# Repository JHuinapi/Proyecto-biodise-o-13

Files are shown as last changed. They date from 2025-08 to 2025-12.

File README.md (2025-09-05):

<table>
   <tr>
      <td valign="top">
         &nbsp;&nbsp;&nbsp;&nbsp;&nbsp;&nbsp;&nbsp;&nbsp;
      </td>
      <td valign ="middle">
         &nbsp;&nbsp;&nbsp;&nbsp;&nbsp;&nbsp;&nbsp;&nbsp;&nbsp;&nbsp;&nbsp;&nbsp;&nbsp;
      </td>
   </tr>
</table>

<h1>Fundamentos de Biodiseño</h1>
Bienvenidos al repositorio del grupo 13 del curso "Fundamentos de biodiseño" horario B403

Tema de interes: Trastornos neurológicos (esclerosis)

Integrantes:
- Mariam Michelle Morocho Bustamante - mariam.morocho@upch.pe
- Alexandra Milagros Mamani Casas - alexandra.mamani@upch.pe
- Luis Antonio Gutierrez Nuñez - luis.gutierrez.n@upch.pe
- Jonatan Esteban Huiñapi Huaman - jonatan.huinapi@upch.pe
- Ricardo Sebastian Murillo Sedano -  ricardo.murillo@upch.pe
- Xavier Alexis Hernandez Jeronimo - xavier.hernandez@upch.pe

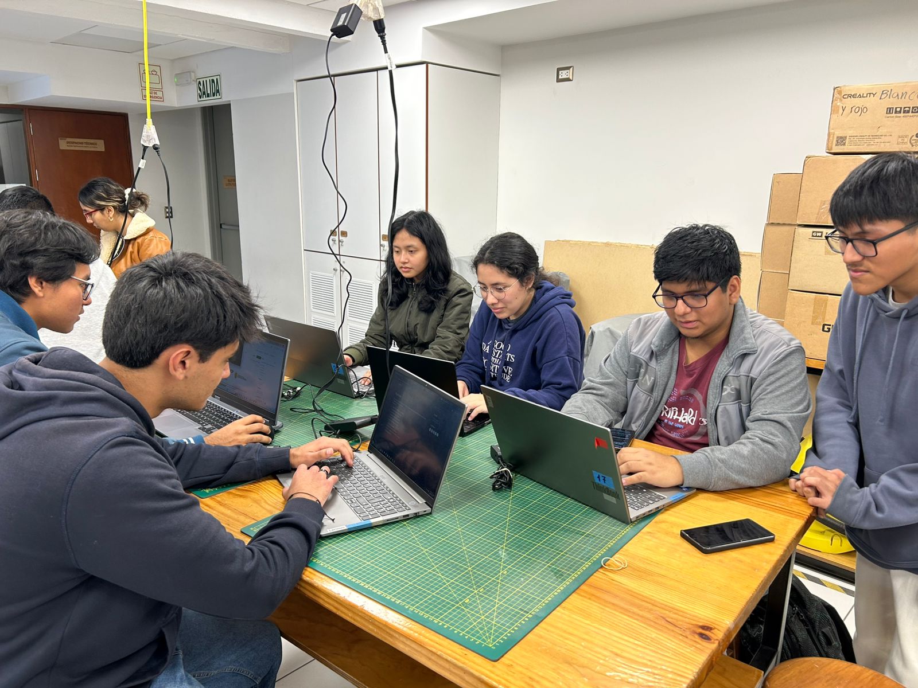
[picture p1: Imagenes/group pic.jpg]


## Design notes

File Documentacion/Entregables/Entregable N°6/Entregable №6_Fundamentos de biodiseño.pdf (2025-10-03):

Entregable №6: Metodología VDI - Parte 1

### 1. Checkpoint 1 – Business Case (¿Por qué hacemos este proyecto?)

a. Situación inicial
¿Cuál es el problema, necesidad o contexto que motiva el desarrollo?

El problema surge a partir de una lesión medular completa de tipo A en el nivel T10 ocasionada en su trabajo como mecánico. A pesar de lo mencionado, presenta una zona de preservación parcial ZPP por lo que retiene algo de sensibilidad y de movimiento de forma parcial y puede flexionar la cadera.
Actualmente, por su lesión el paciente necesita el apoyo de dos bastones canadienses y de dos soportes largos (ortesis) al momento de desplazarse. Estos últimos le brindan estabilidad y pueden trabarse y destrabarse a nivel de la rodilla dependiendo de la acción que necesite hacer el usuario.
El desplazamiento se ve limitado ya que las ortesis se accionan de forma manual requiriendo el apoyo de terceros. Por lo mismo existe la necesidad de optimizar la marcha sobre todo en la zona de la rodilla de forma que es posible reducir su dependencia al momento de trasladarse.
b. Objetivos estratégicos
¿Qué metas técnicas, económicas y organizativas debe cumplir el proyecto?

Este proyecto tiene diversos objetivos, establecidos en base a los problemas cotidianos y dificultades que presentó nuestro paciente. Por el apartado técnico, principalmente se vio necesario incluir de algún modo le ayude a sostenerse y distribuir su peso de una forma que sea más favorable para que las zonas funcionales soporten el peso de su propio cuerpo, por ejemplo, con muletas, un andador, un exoesqueleto, etc. En el caso del paciente planeamos incluir una forma de que pueda controlar del trabe y destrabe de su rodilla con movilidad de manera remota, para evitar las dificultades que incluyen el hacerlo manualmente. Además, el paciente necesitaba saber cómo están posicionadas sus piernas, ya que no posee sensibilidad en estas, y sería primordial para evitar posibles daños en estas. La forma de lograr esto fue prevista a través de sensores que puedan analizar el ángulo de incidencia y la presión o fuerza realizada sobre el piso.

Por el lado económico, se propuso como meta de que el dispositivo no sea muy caro, de esta manera se pensó en un modelo que sea simple y que priorice cumplir con su objetivo, por encima del resto de cosas. En ese sentido se busca un material que sea resistente con el tiempo, que los componentes requieran de poco mantenimiento y que el dispositivo recubra solo zonas esenciales para que no sea muy robusto el modelo, así reduciendo el costo de producción y en consecuencia el de venta. Esto debido a que la mayoría de dispositivos que tratan de suplir con el problema son exoesqueletos u órtesis que resaltan a simple vista por su tamaño, además de ser en su mayoría muy costosas.

Nuestra meta organizativa es brindar una mejor calidad de vida a aquellas personas que hayan perdido la movilidad y que principalmente necesitan de soportes o ayuda para poder ejercer la marcha, brindándoles una alternativa de menor costo y con considerable vida útil.

c. Valor añadido
¿Qué beneficio aporta el sistema (para el usuario, para la empresa, para la sociedad)?

El valor añadido de nuestro sistema se refleja en tres niveles. Para el usuario, el principal beneficio es el incremento de la independencia funcional, ya que el mecanismo de trabe y destrabe optimizado elimina la necesidad de asistencia externa para esa función en particular, permitiendo transiciones más fluidas entre caminar y subir escalones, además se logra de está forma adecuarse a terrenos con más irregularidades. Esto se traduce en una experiencia de marcha más natural, disminuyendo la fatiga y aumentando la confianza en el desplazamiento. Asimismo, la incorporación de materiales adaptados minimiza el riesgo de lesiones por presión y mejora la comodidad durante su uso prolongado, garantizando el uso del dispositivo en la vida diaria. En el caso de la empresa, el prototipo constituye una innovación frente a ortesis tradicionales, al integrar un sistema mecánico de bloqueo automático mediante engranajes y topes que ofrece mayor eficiencia y seguridad estructural en la rodilla. Esta solución, además de ser más práctica para el usuario, se caracteriza por su simplicidad mecánica, lo que facilita tanto su fabricación como su mantenimiento, aumentando el atractivo del producto frente a sistemas más complejos o costosos. De esta forma, no solo presenta un avance técnico, sino también una oportunidad para diferenciarse en el mercado de dispositivos ortopédicos. Finalmente, para la sociedad, el dispositivo aporta un impacto positivo al favorecer la inclusión y movilidad de personas con lesión medular, lo que contribuye a mejorar su participación en actividades cotidianas y a reducir su dependencia de cuidadores o familiares. A nivel sanitario, puede disminuir complicaciones médicas derivadas de la inmovilidad prolongada, como úlceras por presión o problemas musculoesqueléticos, generando así un beneficio en la calidad de vida del paciente y una reducción potencial en los costos asociados a la atención médica. En un sentido más amplio, el proyecto promueve el avance de soluciones biomédicas accesibles e impulsa el desarrollo de tecnologías sociales que buscan mejorar la autonomía y bienestar de esta población.

d. Stakeholders
¿Quiénes son los usuarios, clientes y partes interesadas clave?

Este proyecto está dirigido a personas que han perdido parcialmente la movilidad de sus piernas. Personas que aún pueden caminar, pero que necesitan bastones u otros soportes largos para poder desplazarse, ya que no cuentan con la capacidad de flexionar desde la cadera hacia abajo y, en relación con el tren inferior, únicamente disponen de los flexores de cadera. En otras palabras, el destrabe y trabe de la rodilla depende de una ortesis, dado que la persona no cuenta con la posibilidad de flexionar la pierna por su propia cuenta.

Es por ello que el propósito del proyecto es ofrecerles una manera de caminar más fluida y cómoda. Las ortesis mecánicas tradicionales ayudan a bloquear y desbloquear los ejes que permiten el movimiento al andar, pero muchas veces no son prácticas, pues pueden bloquearse de forma involuntaria y dificultar el paso. Por eso, este proyecto busca brindar una alternativa pensada especialmente para quienes tienen movilidad reducida y han perdido la sensibilidad en la parte inferior del cuerpo.

Asimismo, dentro de las partes interesadas destacamos a la propia familia del usuario, ya que presentar una discapacidad es un golpe duro tanto para la persona que la experimenta como para sus familiares, quienes asumen un peso emocional y una dificultad económica añadida. Del mismo modo, asociaciones, fundaciones y organizaciones que apoyan a personas con discapacidad de bajos recursos también forman parte de los interesados, puesto que, a través de ellas, el trabajo desarrollado puede tener un mayor alcance y permitir que estas personas retomen y realicen de manera más cómoda y rápida actividades tan cotidianas como caminar o subir escaleras.

e. Competencias y equipo
¿Se cuenta con el conocimiento, habilidades y recursos adecuados?

Para poder realizar el proyecto se requiere tener un conocimiento sobre la situación en la que se encuentra el paciente y cuál es la ayuda que requiere específicamente. A partir de estos aspectos se construye una idea de solución, la cual es la automatización del proceso del trabe y destrabe de rodilla facilitado por una órtesis. Para poder construir esta idea se requiere tener conocimiento sobre el funcionamiento del sistema que permite este proceso. Este conocimiento fue adquirido al realizar una exhaustiva revisión de diversas patentes que contaban con esta funcionalidad.
En cuanto a las habilidades necesarias para completar el proyecto, se requiere conocer cómo trabajar con sensores y el sistema Arduino para poder realizar el código que se requiere que sigan estos sensores. Además, para poder realizar el producto se requiere saber cómo manejar algún programa de modelado 3D para poder construir, y posteriormente imprimir, las secciones de la solución que lo requieran.
Los recursos adecuados para poder realizar el proyecto serían sensores para poder calcular el ángulo de flexión de la rodilla, placa bluetooth para facilitar el trabe y destrabe de rodilla, programa Arduino Uno para realizar el código, placa Arduino Uno para ejecutar el código, programa de modelado 3D para poder visualizar el producto y filamentos para impresión 3D en caso se requiera imprimir alguna parte del producto.
f. Planificación inicial
¿Cuál es el cronograma preliminar, presupuesto y posibles riesgos?

El cronograma preliminar iniciará a partir de la semana 7, hasta la semana 16.

Semana | Objetivo
7 | Checkpoint 1- Business Case: Definición de solución y necesidades técnicas, económicas y materiales del producto a realizar en base a la necesidad del paciente.
8 | Checkpoint 2 y 3: Organización de la solución, indicando las características, estructura de funciones, lista de requerimientos, materiales.
9 | Hito N°1
10 | Modelado 3D de elementos propios de la solución.
11 | Prototipado electrónico de solución (parte 1)
12 | Prototipado electrónico de la solución (parte 2)
13 | Integración del prototipado electrónico y piezas 3D (formación de primer prototipo completo)
14 | Validación del prototipo de baja fidelidad con pruebas de uso
15 | Hito N°2
16 | Presentación final del proyecto. Incluye el informe técnico, sustentación oral y presentación de pósters.

Para la realización del presupuesto, cabe recalcar que la realización de esta solución no indica un cambio en el esqueleto de los soportes metálicos y el bastón canadiense que se utilizan en la solución. Se muestran los precios del soporte metálico producido en el INR, con los precios para pacientes con afiliación al SIS, INR, Essalud y seguros privados respectivamente. El usuario, al no poseer sensibilidad en ningún MI, utiliza dos soportes metálicos largos simples y dos bastones canadienses.

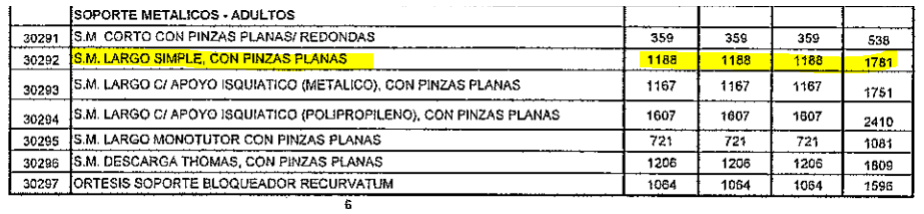
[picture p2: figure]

Fig 1. Precio de soporte metálico largo simple del tarifario INR-2015 [1]

Asimismo, se tomará en cuenta un principio mecánico para realizar el frenado de la rodilla. El cual actuará al obtener la información de los sensores de presión plantar, los cuales pueden ser cubiertos por 4 o 5 sensores de presión (1 Sensor FlexiForce A201-100 (0-445 N) en parte del talón y 3 sensores FSR-402 ( para los metatarsos) para abarcar gran parte del área del pie y cumplir con el rango de medición. Estos serán acompañados con un sensor que mida posición, velocidad y aceleración angular para obtener la fase de marcha del usuario, para este caso, se aplicarán dos sensores MPU 9250, uno ubicado en el muslo y otro ubicado en la tibia, con el fin de obtener las mediciones relativas. Además, es importante considerar un microcontrolador con capacidad de comunicación por Bluetooth como el ESP-32, los cuales irían como maestro (alrededor de la rodilla) y seguidores (en el bastón canadiense y cerca de la planta del pie). Asimismo, se necesitan actuadores como el solenoide pull type sobre un freno simple como el bloqueo de trinquete suizo. Sin embargo, este puede ser modelado en 3D para añadir aberturas para conexión con los actuadores.
Necesita 3 baterías recargables para cada parte del producto, con una grande para abarcar el solenoide y otras más chicas para los sensores plantares y del bastón.

Elemento | Cantidad | Costo unitario | Costo Total (s/.)
Bastón tipo canadiense de PP (adultos) [2] | 2 | 55 | 110
S.M. Largo simple con pinzas planas[1] | 2 | 1781 | 3562
Sensor FlexiForce A201-100 [3] | 1 | 22.95 USD | 80.28
Sensor FSR-402 [4] | 3 | 30 | 90
Sensor MPU 9250 [5] | 2 | 65 | 130
Microcontrolador ESP-32 [6] | 3 | 30 | 90
Solenoide electromagnético JF-0630B [7] | 1 | 21 | 21
Batería lipo 3S 11.4 V | 1 | 102.5 | 102.5
Batería lipo 1S 3.7V | 2 | 23 | 46
Total | | | 4221.28

Finalmente, este producto busca la modificación de uno de los bastones canadienses y uno de los soportes largos, por lo que para un prototipo, se puede prescindir de uno de cada uno, lo cual deja un mínimo de s/.2395,28. Por el lado de los componentes utilizados, se emplearán s/. 559,28 sin considerar costos por material de impresión 3D (PLA) y elementos de bajo costo como las resistencias, placas, cables y cuerdas que conectan a los motores con el bloqueador.

Finalmente, los riesgos se encontrarán en la falla del sistema de frenado, al no propiciar la suficiente fuerza para mantener el bloqueo libre cuando se requiera. La falta de aceptación del paciente debido a la alza en el precio del producto. Así como una baja deficiente resistencia del material de impresión para soportar el bloqueo de la articulación de la rodilla.

Referencia de costos:

1. https://app.inr.gob.pe:444/media/html/transparencia/transparencia%20inr/resoluciones/2015/RD%20122-2015-SA-DG-INR.pdf (https://app.inr.gob.pe:444/media/html/transparencia/transparencia%20inr/resoluciones/2015/RD%20122-2015-SA-DG-INR.pdf)

[1]
“Bateria Lipo 3.7V 600mAh 1S 25C Turnigy Nano-Tech”. Accedido: 2 de octubre
de | 2025. | | [En | línea]. | | Disponible | en:
https://sawers.com.pe/bateria-lipo-38v-520mah-80-160c
[2]
“ESP32 Devkit V1 30P”, Electromanía Perú. Accedido: 2 de octubre de 2025.
[En | | línea]. | | | Disponible | | en:
https://www.electromania.pe/producto/esp32-devkit-v1-30p/
[3]
“Solenoide Electromagnetico 12 VDC 3000mA 10mm Electroiman Solenoide”, Hi-Fi SAC Perú. Accedido: 2 de octubre de 2025. [En línea]. Disponible en: https://hifisac.com/shop/jf-0630b-solenoide-electromagnetico-12-vdc-3000ma-10 mm-electroiman-solenoide-3174 (https://hifisac.com/shop/jf-0630b-solenoide-electromagnetico-12-vdc-3000ma-10mm-electroiman-solenoide-3174)
[4]
“Sensor de Fuerza resistivo FSR402 / FSR406”, MTLAB. Accedido: 2 de octubre
de | 2025. | | [En | línea]. | | Disponible | en:
https://mtlab.pe/producto/sensor-de-fuerza-resistivo-fsr402-fsr406/
[5]
“ORTOPEDIA WONG e-commerce ”:, Ortopedia Wong. Accedido: 2 de octubre
de | 2025. | | [En | línea]. | | Disponible | en:
https://www.ventasortopediawong.pe/producto/baston-canadiense
[6]
“MPU9250: Acelerómetro + Giroscopio + Magnetómetro”, MTLAB. Accedido: 2
de | octubre | de | 2025. | [En | línea]. | Disponible | en:
https://mtlab.pe/producto/mpu9250-acelerometro-giroscopio-magnetometro/[7]
“FlexiForce Pressure Sensor - 100lbs.” Accedido: 2 de octubre de 2025. [En
línea]. | | | | Disponible | | | en:
https://www.sparkfun.com/flexiforce-pressure-sensor-100lbs.html
[8]
“Bateria Lipo DUPU Nanotech de 11.1Voltios 2200mAh 3S 24.4Wh Tamaño:105x35x25mm”, Hi-Fi SAC Perú. Accedido: 2 de octubre de 2025. [En
línea]. | | | | Disponible | | | en:

https://hifisac.com/shop/dupu-25c2200-bateria-lipo-dupu-nanotech-de-11-1voltio s-2200mah-3s-24-4wh-tamano-105x35x25mm-43 (https://hifisac.com/shop/dupu-25c2200-bateria-lipo-dupu-nanotech-de-11-1voltios-2200mah-3s-24-4wh-tamano-105x35x25mm-43)

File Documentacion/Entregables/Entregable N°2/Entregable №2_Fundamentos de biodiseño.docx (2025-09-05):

Entregable №2: Análisis del caso

1. —

1.1. Información Personal:

- Edad: 28
- Género: masculino
- Grado de instrucción: superior universitaria completa
- Trabajo: Actualmente desempleado
- Procedencia: natural de Lima
- Estado civil: soltero, sin hijos
- Regímenes de tratamiento médico o terapéutico y sus objetivos:

Se le pronóstica rehabilitación funcional y neurológica. Los objetivos del tratamiento o terapia médica serían:

- Locomoción independiente en silla de ruedas mecánica simple.
- Manejo funcional paciente y familia, transferencias y actividades de vida diaria .
- Manejo y prevención de complicaciones .
- Orientaciones y apoyo para la adaptación psicosocial y para la rehabilitación profesional .
- Orientación sexual individual .

1.2. Financiamiento:

No se menciona que el paciente esté afiliado a un seguro. Asimismo, no se encuentra trabajando actualmente debido a su lesión por lo que no tendría una fuente de ingresos fija. Puede que cuente con el apoyo financiero de sus familiares. Una de las posibilidades para realizar sus tratamientos o terapias sería afiliarse al Seguro Integral de Salud (SIS) para acceder a un programa integral de rehabilitación y un departamento de lesiones medulares en el IRN.

1.3. Diagnósticos e historial médico:

- Diagnóstico: El diagnóstico principal es un traumatismo de la médula espinal NN C7, AIS “B” por zambullida (T09.3/ W16.3).
- Cirugías pasadas, planes quirúrgicos futuros:

El 2/03/202 4 ,tiene una laminectomía de C7 + fijación anterior. El 07/03/2024 se realiza una artrodesis cervical anterior y entra a UCI hasta el 09/03/2024. Acude al INR por primera vez el 23/05/2024.

- Medicamentos: La medicación habitual es tamsulosina, nitrofurantoína, gabapentina, carbamazepina, baclofeno, diazepam y omeprazol para abordar complicaciones causadas por la lesión.
- Dolor, molestias, quejas o inquietudes: Dolor en el antebrazo derecho con irradiación a mano derecha y en la muñeca izquierda. El dolor es de predominio nocturno que interrumpe el sueño, tipo lancinante. No presenta otras molestias en el sueño y el apetito, sed y ánimo se han conservado.
- Función motora oral para el habla y la deglución: Comunicación mediante lenguaje oral adecuado y deglución conservada.
- Estado cardíaco y respiratorio, resistencia:
- Aparato respiratorio: patrón abdominal torácico, ventila espontáneamente ambos campos pulmonares, con buen pasaje del murmullo vesicular y sin ruidos agregados.
- Corazón: Ruidos cardiacos rítmicos, no se auscultan soplos.
- Vascular: Sin signos clínicos de trombosis venosa en las extremidades inferiores.
- Abdomen: Globuloso, blando, no doloroso. No se palpan visceromegalias
- Función intestinal y vesical: Correspondiente a la función vesical, se inició por micción por sonda vesical permanente, actualmente evolucionó a un cateterismo intermitente 5 veces al día realizado por cuidador y familiar. En cuanto a la función intestinal, tiene una frecuencia evacuatoria de sus deposiciones 2 veces al día en pañal sin horario. Se menciona que no cuenta con un baño adaptado.

1.4. Estado psicosocial:

En el informe se comenta que el paciente se encuentra recibiendo orientaciones y apoyo para la adaptación psicosocial. Se comenta que hay un manejo funcional paciente y familiar.

1.5. Estado neuromuscular y musculoesquelético:

El paciente presenta limitación importante en la movilidad, con actividad voluntaria disminuida en los miembros superiores y ausente en los miembros inferiores, mientras que los rangos pasivos se mantienen relativamente funcionales. Se observa pérdida de masa muscular con hipotrofia moderada en las cuatro extremidades y un aumento marcado del tono, predominante en los miembros superiores, con registro de Ashworth 3 y Penn 3. La sensibilidad superficial se conserva hasta los niveles C7 y C8 de forma bilateral y también en los segmentos sacros S4-S5, acompañada de SAP positivo. Los reflejos muestran respuesta piramidal con Babinsky bilateral positivo y clonus bilateral positivo, además de reflejos sacros perianal y bulbocavernoso presentes, tono esfinteriano aumentado y reflejo de la tos conservado. La coordinación permanece funcional en los segmentos donde existe movimiento voluntario, sin contracción voluntaria del esfínter anal externo y con signo de Beevor negativo.

1.6. Afección de la piel:

En el examen clínico no se evidenciaron infecciones en la piel ni cicatrices relevantes; la piel se describe rosada, sin palidez ni cambios de coloración. Se observa hipotrofia moderada en los cuatro miembros junto con un aumento del tono muscular, hallazgos que se relacionan con la disminución de la movilidad activa y la dependencia funcional del paciente, de esta forma cambiando la textura de los tejidos blandos al hacerlos más flácidos y menos voluminosos. No se han desarrollado úlceras por presión hasta el momento, la condición de inmovilidad y el compromiso neurológico constituyen factores de alto riesgo para su aparición futura.

1.7. Función sensorial/ Habla, lenguaje y comunicación:

El paciente presenta sensibilidad superficial conservada hasta los niveles C7 y C8 de manera bilateral, con sensibilidad en los segmentos sacros S4-S5 positiva y SAP positivo. El lenguaje oral es adecuado, la comunicación se mantiene conservada y la deglución se encuentra preservada, sin alteraciones aparentes de los pares craneales.

1.8. Desempeño funcional, de habilidades y de tareas:

El paciente es asistido por personal y familiares en el manejo de su funcionalidad. Actualmente requiere cateterismo intermitente cinco veces al día, procedimiento realizado por un cuidador o familiar, además del uso de pañal durante la noche. En actividades de la vida diaria (AVD) es dependiente en su totalidad, aludiendo a dependencia en higiene, alimentación, tareas y actividades de mesa, además de la movilidad dependiente realizada por dos personas con uso de una tabla de traslación al no lograr la sedestación. Su movilidad se encuentra limitada, y es necesario el uso de la silla de ruedas para el desplazamiento, pero aún no alcanza independencia en su manejo.

1.9. Movilidad personal:

La movilidad personal es restringida, la deambulación es un acto no autónomo para el paciente debido al apoyo requerido para movilizarse con la silla de ruedas. Asimismo los traslados presentan complicaciones y son necesarias dos personas para manejar una tabla de translación y el apoyo constante de un cuidador/familiar para las actividades diarias. Dando por entendido el uso constante de la silla de ruedas para la movilización y traslación, esto afecta en aspectos como el cambio de peso debido a la condición de hipotrofia y el aumento del tono muscular.

1.10. Transporte comunitario:

El paciente es natural de Lima. No se aclara si actualmente se encuentra residiendo en la ciudad. Si este es el caso, probablemente se traslade en autobús, corredor, metropolitano, línea 1 del metro o taxis si no cuenta con un vehículo propio. Dichos medios de transporte en varias ocasiones no se encuentran adaptados para trasladar a personas con lesiones de médula espinal. También podría usar servicios de transporte médico como ambulancias no emergentes.

1.11. Entornos:

Se comenta que en su hogar no cuenta con la accesibilidad a un baño adaptado para su condición. Además, es importante mencionar la poca accesibilidad a lugares públicos que tienen las personas que se movilizan en silla de ruedas en el Perú; como se menciona en una nota de prensa del Ministerio de viviendo, construcción y saneamiento, el 31.5% de peruanos con alguna discapacidad física presentan dificultades para ingresar a espacios públicos [1].

1.12. Historial de equipos anteriores:

En el caso del paciente solo se especifica el uso de una silla de ruedas a medida con cojín de asiento adaptado, una tabla de transferencia cargada por dos personas para su desplazamiento, debido a que no lograba la sedestación.Y hizo uso de una sonda vesical de manera continua para la micción. Sin embargo, el paciente carece de un baño diseñado para sus necesidades. El caso clínico no presenta información acerca de los gustos, disgustos y tolerancia al cambio del paciente acerca de la tecnología. Pero se intuye que una de sus principales preocupaciones es su dependencia a sus familiares.

1.13. Equipo actual:

El paciente hace uso de una silla de ruedas mecánica simple para su movilidad con un tiempo de vida útil aproximado de 3 a 5 años, el paciente tiene como meta lograr locomoción independiente con esta. También recibe cateterismo al menos 5 veces al día, realizado por parte de un familiar o cuidador. Además, usa pañales y papagayo para su incontinencia nocturna y excreción. No se menciona el uso de algún otro equipo ni se especifica el modelo de la silla de ruedas.

2. Resumen de la información del paciente/caso

2.1. Usuario/Paciente: Describe las habilidades y capacidades de la persona con discapacidad

El paciente es un varón de 28 años con formación universitaria como ingeniero. A pesar de su lesión medular, conserva intactas sus capacidades cognitivas y de comunicación. Se encuentra lúcido, orientado en tiempo, espacio y persona, y se comunica adecuadamente a través del lenguaje oral. Sus funciones biológicas como el apetito, la sed y el ánimo están conservadas, y su sistema respiratorio funciona de manera espontánea sin asistencia.

Sus capacidades motoras se centran en los miembros superiores. Posee fuerza muscular completa (calificada en 5/5) para flexionar los codos y para realizar la dorsiflexión (extensión) de las muñecas. También puede extender los codos contra la gravedad (fuerza 3/3). A nivel sensorial, tiene sensibilidad superficial conservada hasta el nivel C7/C8 y, de manera crucial, presenta sensibilidad en los segmentos sacros (S4-S5), lo que clasifica su lesión como incompleta. Además, presenta erecciones y reflejos sacros como el perianal y el bulbocavernoso. Sin embargo, no tiene movilidad activa en los miembros inferiores ni contracción voluntaria del esfínter anal.

2.2. Actividad: Describe el conjunto de tareas a realizar por la persona con discapacidad

Actualmente, el paciente es dependiente para la realización de todas sus Actividades de la Vida Diaria (AVD). Las tareas cotidianas en las que participa o que se le realizan son:

• Movilidad y Transferencias: El hecho de movilidad requiere la participación de dos personas que lo asistan. No logra la tarea de sentarse por sí mismo.

• Manejo de la vejiga e intestinos: Una tarea programada y esencial es la gestión de la micción, que se realiza mediante cateterismo intermitente cinco veces al día, llevado a cabo por un cuidador o familiar. El manejo de las deposiciones es diario pero aún no sigue un horario establecido.

• Manejo del Dolor: Una tarea constante es sobrellevar en el antebrazo derecho con irradiación en su mano derecha y muñeca izquierda que es más intenso por la noche e interrumpe su sueño.

2.3. Contexto: Describe el entorno o contexto social, cultural y físico que rodea el entorno en el que debe realizarse la actividad.

El paciente es un adulto joven, soltero, sin hijos, procedente de Lima, con formación universitaria completa como ingeniero. El entorno físico inmediato no está completamente adaptado a sus necesidades, pues no cuenta con un baño adaptado en su hogar. Vive con su familia, la cual participa activamente en sus cuidados, como en la realización del cateterismo intermitente 5 veces al día. Para las movilizaciones, como las transferencias, depende del apoyo de dos personas.

2.4. Tecnología: dispositivos o estrategias utilizadas para cerrar la brecha entre las

capacidades de la persona y las demandas del entorno

Para suplir la brecha entre sus capacidades y las demandas del entorno, el paciente utiliza una combinación de dispositivos y estrategias:

• Dispositivos de movilidad y soporte: Utiliza una silla de ruedas a medida con un cojín de asiento adaptado y una tabla de traslación para las transferencias.

• Dispositivos para el manejo de funciones biológicas: Usa pañales para la incontinencia urinaria y fecal y un orinal (papagayo) durante la noche.

• Estrategias de manejo de salud: Se le realiza cateterismo vesical intermitente cinco veces al día para el manejo de la vejiga. Además, sigue un régimen farmacológico que incluye medicamentos como Tamsulosina, gabapentina, baclofeno y diazepam para el manejo de su condición.

Referencias:

[1] Oficina General de Comunicaciones, “Más del 30% de peruanos con discapacidad tiene problemas para su desarrollo profesional debido a barreras en sus Ciudades,” Noticias - Ministerio de Vivienda, Construcción y Saneamiento - Plataforma del Estado Peruano, https://www.gob.pe/institucion/vivienda/noticias/658298-mas-del-30-de-peruanos-con-discapacidad-tiene-problemas-para-su-desarrollo-profesional-debido-a-barreras-en-s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

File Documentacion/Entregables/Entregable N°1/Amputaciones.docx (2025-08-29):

Amputaciones

## 1. Ficha de la enfermedad

Las amputaciones son definidas como un procedimiento o condición médica de extirpar una extremidad o parte de ella. Esta condición está relacionada directamente con un perjuicio al sistema musculoesquelético[1].

Anatomía y fisiología de la amputación:

El cuerpo humano consta de 2 extremidades inferiores y 2 extremidades superiores mayores, las cuales hacen referencia a los brazos y las piernas. Estos están formados por huesos, músculos, vasos sanguíneos y nervios del sistema nervioso periférico. Además, se le conoce a las articulaciones como zonas que permiten la movilidad entre huesos y presentan una cavidad articular que contiene líquido sinovial, en algunos de ellos se llegan a desarrollar discos articulares fibrocartilaginosos, como en en el nivel de la rodilla, al presentarse superficies articulares incongruente[2]. En ese sentido, existen diversos tipos de amputaciones según el nivel de corte, clasificándolos en mayores o menores y superior o inferior. Las amputaciones mayores son a partir del nivel de tobillo y muñeca, mientras que las amputaciones menores son llamadas amputaciones parciales de mano o de pie[3].

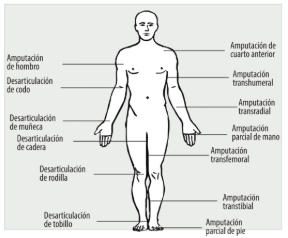
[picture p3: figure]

Fig.1 Tipos de amputación [3]

Al momento de realizar el procedimiento, se considera importante considerar las partes salvables de la extremidad, la obtención de de un muñón sensible y con buena troficidad , así como la prevención de neuromas dolorosos y de rigidez articular[4]. Esto con el objetivo de restaurar la extremidad hasta el nivel compatible de vida de los tejidos y conseguir que el paciente vuelva a reinsertarse en la sociedad[5].

2. Factores y análisis de la enfermedad

Factores de riesgo principales:

Las amputaciones representan un gran problema para el desarrollo de la marcha y de actividades del día a día, y dentro de las causas principales por las que se dan es debido a accidentes de tránsito, laborales, enfermedades crónicas como enfermedades arteriales, complicaciones diabéticas, cáncer o infecciones graves. [6]

La diabetes mellitus se vuelve un tema importante a estudiar y analizar en amputaciones, puesto que la diabetes desencadena en la aparición del pie diabético, el cual es la complicación más común y responsable de un gran número de hospitalizaciones y amputaciones no traumáticas de miembros inferiores en el 90% de los casos. [7]

Por otro lado, dentro de las amputaciones de origen traumático, en su mayoría se dan por dos motivos principales, los cuales son los accidentes automovilísticos y los laborales, dentro de los accidentes laborales se destaca que uno de los principales factor de riesgo es la falta de formación adecuada, aunque también se pueden suscitar accidentes a causa de una maquinaria defectuosa o no protegida. [6]

Manifestaciones clínicas más relevantes:

Dentro de las manifestaciones clínicas más relevantes existentes tras una amputación, se encuentra la alteración en la mecánica y adaptación anatómica, puesto que en las amputaciones de miembro inferior, la alineación normal está dictado por la línea axis del fémur, la cual pasa por la cabeza femoral hasta el centro de la rodilla para terminar en medio del tobillo. Como resultado de una amputación transfemoral, la alineación anatómica se encuentra alterada por que el fémur residual no mantiene las mismas proporciones que poseía antes de la amputación. [8]

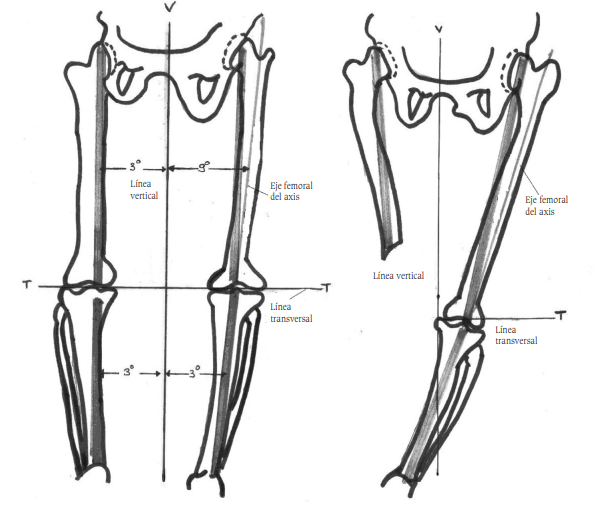
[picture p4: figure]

Fig. 2. Representación de cambio de eje de simetría del amputado [8]

La rodilla cumple un papel clave en la biomecánica de la marcha y en los traslados, ya que ayuda a reducir el desplazamiento del centro de gravedad. Cuando esta articulación falta, se pierden inserciones musculares importantes que modifican el patrón normal de locomoción. Esto provoca que la marcha sea menos eficiente y que el gasto energético aumente entre un 68% y 100% por la ausencia de los músculos aductores. Además, se ven afectados la propiocepción, el equilibrio y la capacidad para realizar transferencias. [8]

Breve nota sobre impacto funcional en la vida diaria :

La amputación si bien permite dar solución a complicaciones clínicas , esto no la exenta de ser una respuesta bastante dolorosa y complicada para la persona que afronta la amputación, la pérdida de una extremidad trae consigo un sinfín de retos nuevos los cuales una persona no se encuentra del todo preparado, la limitación física no permite a las personas que perdieron una extremidad desarrollar ciertos trabajos, lo cual limita su campo laboral y a su vez enfrentan problemas relacionados al aspecto psicológico, ya que la pérdida de una extremidad impacta en la percepción de la imagen corporal, creando en sí malestar y ansiedad por la nueva imagen[9].

3. Prevención, diagnóstico, tratamiento y monitoreo

Prevención

Las amputaciones pueden ser ocasionadas por ciertas enfermedades, entre ellas la diabetes, la cual puede llegar a dañar los nervios, lo que no permitiría que el paciente note las heridas o úlceras que haya en sus pies. La amputación del miembro inferior debido a la diabetes puede ocurrir, sin embargo, este puede ser prevenido al hacer chequeos frecuentes del estado en el que se encuentra el pie del paciente y realizando un cuidado constante de las heridas que se presenten [10] (https://www.zotero.org/google-docs/?broken=aLp53o). Otras enfermedades que pueden llevar a la amputación de un miembro son las enfermedades vasculares, por ejemplo, la enfermedad vascular periférica (EVP), en la cual los vasos sanguíneos se ven obstruidos por grasa y colesterol, lo que no permite un flujo adecuado de la sangre. En casos graves, esta enfermedad puede llevar a la muerte de tejidos que podría terminar en una amputación. Con el fin de prevenir esta enfermedad se recomienda no fumar, mantener un nivel adecuado de colesterol y revisar que la presión arterial mantenga un nivel adecuado. [11]

Diagnóstico

Si bien la amputación no es una enfermedad propiamente dicha, la decisión de proceder con este procedimiento se basa en la presencia de ciertos factores presentes en la diabetes o enfermedades causales. La presencia úlcera isquémica infectada, abscesos, gangrena son considerados factores predisponentes, mientras que una infección y necrosis tisular progresiva son agravantes de la situación del paciente, lo que conforma un factor decisivo para realizarse la amputación[12] (https://www.zotero.org/google-docs/?broken=3JOo04).

Tratamiento

En el caso de amputaciones, por lo general, se hace uso de prótesis que ocupan el lugar del miembro perdido. Con el fin de que el paciente se sienta cómodo con la prótesis se requiere un buen encaje de la misma que no genere daños a la piel del paciente. Para evitar estos daños que podrían ocurrir, se debe tener una prótesis hecha a la medida del paciente y procurar que el paciente mantenga una dieta saludable para evitar que el cambio de peso corporal genere problemas con el encaje de la prótesis. Si el paciente hace uso de una prótesis de miembro inferior también es importante mantener la alineación del cuerpo [13] (https://www.zotero.org/google-docs/?broken=P1DldN).

Monitoreo

Es necesario hacer un monitoreo constante al paciente para poder ver que el socket de la prótesis no esté generando ninguna herida en la sección de piel con la que choca. En el caso de los pacientes con prótesis que tienen diabetes también es necesario realizar monitoreos regulares de su glucemia para evitar una enfermedad vascular y permitir el flujo sanguíneo en la piel[13] (https://www.zotero.org/google-docs/?broken=S6nr6M).

4. Reflexión ingenieril

Las investigaciones en base a usuarios amputados se enfocan principalmente en la calidad de vida y el uso de prótesis como solución, más la problemática que se logra evidenciar es respecto a los problemas en el uso constante de una prótesis, provocada por el socket. Debido a que su papel es crítico, pues actúa como la interfaz directa entre el muñón y la prótesis. Un estudio de percepción con pacientes y profesionales de la salud demostró que el ajuste del socket fue considerado el factor más influyente en la rehabilitación, afectando de manera directa la calidad de vida y la capacidad de realizar actividades cotidianas [14]. Estas dificultades no son menores, ya que se relacionan con tasas elevadas de abandono. En investigaciones multicéntricas se ha reportado que entre un 11 % y un 22 % de los pacientes dejan de usar su prótesis en el primer año posterior a la amputación, siendo el mal ajuste del socket una de las causas principales [15]. De forma complementaria, revisiones sistemáticas muestran que la incomodidad asociada al socket es un determinante recurrente del rechazo protésico, con tasas de abandono de hasta 45 % en ciertos grupos poblacionales [16].

En consecuencia, la evidencia señala que la mejora en el diseño y la adaptabilidad del socket no es simplemente un aspecto técnico, sino una necesidad prioritaria para garantizar la adherencia, la funcionalidad y la verdadera integración de la prótesis en la vida del paciente

5. Bibliografía:

[1] (https://www.zotero.org/google-docs/?broken=zTa6Ac) D. Z. C. Garcia y L. B. Palma, «Rehabilitación cardiaca en paciente con amputación transfemoral secundaria a patología metabólica, reporte de caso», (https://www.zotero.org/google-docs/?broken=S66MCt)Investig. En Discapac. (https://www.zotero.org/google-docs/?broken=S66MCt), vol. 10, n.o S1, pp. s35-s35, oct. 2024. (https://www.zotero.org/google-docs/?broken=S66MCt)

[2] (https://www.zotero.org/google-docs/?broken=3rKaZG) J. W. Rohen, (https://www.zotero.org/google-docs/?broken=H9IjKG)Atlas de anatomía humana: Estudio fotográfico del cuerpo humano (https://www.zotero.org/google-docs/?broken=H9IjKG). Elsevier Health Sciences, 2021. (https://www.zotero.org/google-docs/?broken=H9IjKG)

[3] (https://www.zotero.org/google-docs/?broken=RwK2Dq) F. O. Corredor, M. R. Roncancio, y J. C. M. Pulido, (https://www.zotero.org/google-docs/?broken=GDVqGp)Texto de medicina física y rehabilitación (https://www.zotero.org/google-docs/?broken=GDVqGp). Editorial El Manual Moderno, 2022. (https://www.zotero.org/google-docs/?broken=GDVqGp)

[4] (https://www.zotero.org/google-docs/?broken=NfwLaf) L. Mathieu, L. Borrini, y J.-C. Murison, «Amputaciones y desarticulaciones de los miembros: miembro superior», (https://www.zotero.org/google-docs/?broken=xrBaZy)EMC - Téc. Quirúrgicas - Ortop. Traumatol. (https://www.zotero.org/google-docs/?broken=xrBaZy), vol. 13, n. (https://www.zotero.org/google-docs/?broken=xrBaZy)o (https://www.zotero.org/google-docs/?broken=xrBaZy) 4, pp. 1-18, dic. 2021, doi: 10.1016/S2211-033X(21)45768-3. (https://www.zotero.org/google-docs/?broken=xrBaZy)

[5] (https://www.zotero.org/google-docs/?broken=kXwQ3R) S. Clusa Barbastro y A. Coarasa Liron de Robles, (https://www.zotero.org/google-docs/?broken=2q7KBx)Plan de intervención de fisioterapia en una amputación supracondílea de miembro inferior (https://www.zotero.org/google-docs/?broken=2q7KBx). Zaragoza: Universidad de Zaragoza, 2016. (https://www.zotero.org/google-docs/?broken=2q7KBx)

[6] (https://www.zotero.org/google-docs/?broken=OezmVp) «Causas de Amputación: Enfermedades y Factores de Riesgo | PrimeCare». Accedido: 28 de agosto de 2025. [En línea]. Disponible en: https://primecareprosthetics.com/es/blog/what-causes-amputation-causes-symptoms-and-risk-factors-of-limb-loss (https://www.zotero.org/google-docs/?broken=yjzdzQ)

[7] (https://www.zotero.org/google-docs/?broken=Nxssej) «Factores de riesgo asociados a las amputaciones derivadas RISK | Revista Científica UMAX». Accedido: 28 de agosto de 2025. [En línea]. Disponible en: (https://www.zotero.org/google-docs/?broken=HHnoMM)https://revista.umax.edu.py/index.php/rcumax/article/view/15 (https://www.zotero.org/google-docs/?broken=HHnoMM)

[8] (https://www.zotero.org/google-docs/?broken=jcBnfS) M. L. Ocampo, L. M. Henao, y L. Vásquez, «AMPUTACIÓN DE MIEMBRO INFERIOR: CAMBIOS FUNCIONALES, INMOVILIZACIÓN Y ACTIVIDAD FÍSICA». (https://www.zotero.org/google-docs/?broken=9icC0v)

[9] A. de M. Dummar, “Amputación y salud mental: una revisión sistemática Amputation and mental health: a systematic review”, Universidad de Oviedo, 2021. [En línea]. Disponible en: (https://digibuo.uniovi.es/dspace/bitstream/handle/10651/60268/TFM_AlinedeMesquitaDummar.pdf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)https://digibuo.uniovi.es/dspace/bitstream/handle/10651/60268/TFM_AlinedeMesquitaDummar.pdf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

[10] (https://www.zotero.org/google-docs/?broken=lXYZjq) «Rehabilitación para la amputación de la pierna - Temas especiales», Manual MSD versión para profesionales. Accedido: 28 de agosto de 2025. [En línea]. Disponible en: (https://www.zotero.org/google-docs/?broken=zzy0eH)https://www.msdmanuals.com/es/professional/temas-especiales/rehabilitación/rehabilitación-para-la-amputación-de-la-pierna (https://www.zotero.org/google-docs/?broken=zzy0eH)

[11] MedlinePlus en español [Internet]. Bethesda (MD): Biblioteca Nacional de Medicina (EE. UU.) [actualizado 20 de mayo 2023]. Enfermedad arterial periférica. Accedido: 28 ago. 2025. Disponible en: https://medlineplus.gov/spanish/peripheralarterialdisease.html#

[12] (https://www.zotero.org/google-docs/?broken=NiPyUl) O. Escalante Padrón (https://www.zotero.org/google-docs/?broken=8KKlcX)et al. (https://www.zotero.org/google-docs/?broken=8KKlcX), «Factores pronósticos de amputación mayor en pacientes con pie diabético sometidos a cirugía», (https://www.zotero.org/google-docs/?broken=8KKlcX)Rev. Cuba. Angiol. Cir. Vasc. (https://www.zotero.org/google-docs/?broken=8KKlcX), vol. 21, n. (https://www.zotero.org/google-docs/?broken=8KKlcX)o (https://www.zotero.org/google-docs/?broken=8KKlcX) 3, dic. 2020, Accedido: 28 de agosto de 2025. [En línea]. Disponible en: (https://www.zotero.org/google-docs/?broken=8KKlcX)http://scielo.sld.cu/scielo.php?script=sci_abstract&pid=S1682-00372020000300005&lng=es&nrm=iso&tlng=pt (https://www.zotero.org/google-docs/?broken=8KKlcX)

[13] (https://www.zotero.org/google-docs/?broken=Kbo8k4) CDCespanol, «Cómo prevenir las amputaciones relacionadas con la diabetes», Diabetes. Accedido: 28 de agosto de 2025. [En línea]. Disponible en (https://www.zotero.org/google-docs/?broken=cYJO0c): (https://www.zotero.org/google-docs/?broken=cYJO0c)https://www.cdc.gov/diabetes/es/diabetes-complications/como-prevenir-las-amputaciones-relacionadas-con-la-diabetes.html (https://www.zotero.org/google-docs/?broken=cYJO0c)

[ (https://www.zotero.org/google-docs/?broken=QFMTRm)14] A. Al-Fakih et al., “Socket fit comfort and its impact on quality of life and rehabilitation: a mixed-methods study,” Prosthet. Orthot. Int., vol. 45, no. 1, pp. 18–28, 2021. [En línea]. Available: (https://pubmed.ncbi.nlm.nih.gov/33543086)https://pubmed.ncbi.nlm.nih.gov/33543086

[15] J. Kahle, E. Highsmith, and R. Hubbard, “Prosthetic abandonment in lower limb amputees: a multicenter survey,” Prosthet. Orthot. Int., vol. 47, no. 3, pp. 213–223, 2023. [En línea]. Available: https://pmc.ncbi.nlm.nih.gov/articles/PMC10443512

[16] J. Biddiss and T. Chau, “Upper limb prosthesis use and abandonment: a survey of the last 25 years,” Prosthet. Orthot. Int., vol. 31, no. 3, pp. 236–257, 2007. [En línea]. Available: (https://pmc.ncbi.nlm.nih.gov/articles/PMC7340716)https://pmc.ncbi.nlm.nih.gov/articles/PMC7340716

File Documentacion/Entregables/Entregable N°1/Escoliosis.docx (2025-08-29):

Ficha de la enfermedad

-Nombre de la enfermedad: Escoliosis

-Sistema afectado: Sistema musculoesquelético

-Descripción anatómica/fisiológica:

La escoliosis consiste en una deformidad tridimensional de la columna vertebral y del tronco. Se caracteriza por una curvatura lateral en forma de S o C con un ángulo de Cobb superior a los 10° propio de las curvas ligeras y naturales de la columna. La misma se encuentra acompañada por una rotación vertebral en un plano transversal. Así mismo, la escoliosis afecta al tronco al originar una prominencia costal visible durante la prueba de flexión hacia adelante de Adams.[1] [2]

Factores y análisis de la enfermedad

-Factores de riesgo principales:

Los principales factores de riesgo de la escoliosis son su etiología desconocida (Idiopática). La escoliosis idiopática, el tipo más común entre infantes y adolescentes, tiene una etiología incierta a pesar de las investigaciones exhaustivas sobre factores genéticos y neurológicos. Otro factor es el género. Se ha reportado que las niñas y mujeres tienen más probabilidad de sufrir de escoliosis. De la misma manera, los períodos de crecimiento activo son críticos para la progresión lo que significa que la escoliosis en las personas en crecimiento como niños o adolescente puede empeorar si no se acogen medidas como el uso de corset para evitar curvaturas de la columna más graves. Por último, la ausencia de locomoción cuadrúpeda puede influir en la retención de reflejos y por ende aumentar el riesgo de escoliosis.[2][3]

Existen otros tipo de escoliosis como la congénita que se produce debido a una formación inapropiada de las costillas o vértebras del bebé y la neuromuscular que es causada por un problema en el sistema nervioso que afecta los músculos.[3]

-Manifestaciones clínicas más relevantes:

Asimetría del tronco y los hombros:

Se puede apreciar un hombro más alto que el otro.

Una cadera puede estar más alta o abultada que la otra.

Un omóplato (o "paletilla") puede ser más alto o abultado que el otro.

La cabeza puede no estar centrada con respecto a las caderas.

Al estar de pie con los brazos colgando, el espacio entre un brazo y el tronco puede ser mayor a un lado que al otro.

La pelvis puede aparecer inclinada.

Curvatura visible de la columna: La columna vertebral se observa curvada hacia un lado, luciendo como una letra C o S. [4]

Prominencia costal o giba: Durante la prueba de flexión hacia adelante de Adams, que consiste en agacharse con las piernas estiradas hasta que la espalda quede horizontal, un lado de la espalda puede estar más alto o abultado que el otro. [4]

Dolor:

Dolor de espalda o lumbago que puede extenderse hacia las piernas.

Dolor en los hombros.

Contracturas musculares.

Fatiga o debilidad: Sensación de debilidad o cansancio en la columna después de permanecer de pie o sentado por un tiempo prolongado.

Problemas respiratorios: En casos de escoliosis grave, puede presentarse dificultad para respirar o sentarse. [4]

-Impacto funcional en la vida diaria:

La escoliosis puede tener un impacto significativo en la vida diaria de las personas ya que afecta tanto sus capacidades físicas como su bienestar. Los dolores constantes de espalda o lumbago, la sensación de cansancio en la columna y la dificultad para respirar o sentarse tienen un impacto negativo en las actividades diarias como el trabajo o estudio así como ocasiona que las personas estén en un estado de dolor e incomodidad constante.[2][4]

Así mismo, las escoliosis y el uso de un corsé pueden provocar baja autoestima en los niños y adolescentes. Lo mismo puede ocasionar una baja adherencia a tratamientos como el uso de corsés rígidos y los programas de ejercicio.[2]

Prevención, diagnóstico, tratamiento y monitoreo

- Prevención:

La prevención de la escoliosis se centra en una detección temprana para evitar la progresión de la curvatura de la columna. En este sentido, los exámenes médicos rutinarios y las pruebas son fundamentales. Otra medida es el fortalecimiento muscular a través del ejercicio para estabilizar la curvatura de la columna. [3][4]

- Diagnóstico:

El diagnóstico de la escoliosis consiste en exámenes físicos, la observación de síntomas visibles y pruebas de imagen. En los exámenes físicos se le pedirá al paciente que se agache hacia adelante (prueba de inclinación de Adams) facilitando la observación de la columna y detección de signos de asimetría. También se puede diagnosticar la escoliosis a partir de sus síntomas ya anteriormente mencionados. Por último, las pruebas de imagen como radiografías de la columna vertebral son cruciales para confirmar la desviación y valorar el grado de la curvatura (en grados Cobb). La escoliosis se diagnostica cuando hay una curvatura radiográfica con un ángulo de Cobb mayor de 10°. Otras pruebas de imágenes usadas para el diagnóstico son la resonancia magnética (RM) de la columna, tomografía computarizada (TC) de la columna y algunas alternativas de imagen sin radiación como el ultrasonido. En este último, se han creado ecuaciones para calcular el ángulo de Cobb a partir de mediciones de ultrasonido ya que normalmente se subestima sistemáticamente este valor.[2][3]

- Tratamiento:

El tratamiento actual consiste en el uso de corsés (tratamiento ortopédico), los ejercicios específicos y, en algunos casos, la cirugía. Uno de los métodos de tratamiento más comunes es el uso de corsés (ortesis). Los mismos son más eficaces para tratar curvas de menos de 40 grados. Algunos estudios incluso muestran resultados positivos para curvas superiores a 40° o 45° en pacientes que rechazan la cirugía. Algunas consideraciones que se deben tener en cuenta cuando se opta por este método es la adherencia del paciente para lograr una mayor eficacia. Se ha demostrado que usar el corsé más de 18 horas al día se asocia con la evitación de la cirugía, menor progresión y mayores tasas de mejora. Existen numerosos tipos de corsés que se clasifican según su anatomía, rigidez (muy rígido, rígido, elástico), plano correctivo principal (frontal, sagital, transversal, combinaciones de estos, o tridimensional), construcción, cierre y acción primaria (flexión, de torsión, elongación, movimiento, empuje, tres puntos). [3]

Los ejercicios y la rehabilitación por sí solos no reducen la magnitud de la curva o el riesgo de progresión sino que se utilizan como tratamiento complementario para mejorar la postura y fortalecer los músculos. Por último, la cirugía se indica en pacientes en edad de crecimiento con curvas de más de 60 grados o entre 40 y 60 grados con progresión evidente a pesar del tratamiento ortopédico. Cabe resaltar que la cirugía no es necesaria en el 85-90% de los casos.[3] [4]

- Monitoreo:

El monitoreo de la escoliosis consiste en las revisiones médicas regulares, revisar que se sigan los tratamientos indicados y en observar el estado de los pacientes que optaron por la cirugía. Para la mayoría de los casos de escoliosis idiopática que no requieren tratamiento inmediato sino que se realizan exámenes de seguimiento aproximadamente cada 6 meses. La adherencia del paciente al tiempo de uso prescrito del corsé es crucial para su efectividad por lo que la monitorización objetiva se hace fundamental ya sea mediante sensores embebidos en el corsé (monitores de cumplimiento) o mediante un asesoramiento basado en datos objetivos. Así mismo, después de una cirugía existen varios aspectos importantes a considerar como el uso de corsé post-quirúrgico para mantener la columna vertebral estable o la fusión vertebral y estabilidad permanente.[3] [4]

Reflexión ingenieril:

El diagnóstico, tratamiento y monitoreo de la escoliosis brinda oportunidades para innovar mediante la ingeniería a través el desarrollo de sensores vestibles (Wearables) para el monitoreo, el uso de la inteligencia artificial y aprendizaje automático (Machine Learning) en el diagnóstico por Imágenes, el uso de la Impresión 3D y la elaboración de órtesis (Corsés) Inteligentes o hechas a partir de nuevos materiales.

[1] S. Negrini, A. G. Aulisa, P. Cerny, et al., "The classification of scoliosis braces developed by SOSORT with SRS, ISPO, and POSNA and approved by ESPRM," Eur. Spine J., vol. 31, pp. 1–10, 2022, doi: 10.1007/s00586-022-07131-z.

[2] Escoliosis, MedlinePlus, 2023. [Online]. Available: https://medlineplus.gov/spanish/ency/article/001241.htm. [Accessed: August 27, 2025].

[3] S. L. Weinstein, L. Dolan, J. Cheng, A. Danielsson, and J. Morcuende, "Adolescent idiopathic scoliosis," Scoliosis, vol. 11, Art. no. 23, 2016, doi: 10.1186/s13013-016-0061-3.

[4] Escoliosis, Clínica Universidad de Navarra, 2023. [Online]. Available: http://cun.es/enfermedades-tratamientos/enfermedades/escoliosis. [Accessed: August 27, 2025].

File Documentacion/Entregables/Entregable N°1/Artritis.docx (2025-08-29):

Artritis

## 1. Ficha de la enfermedad

Nombre de la enfermedad: Artritis

Sistema afectado: sistema musculoesquelético

Descripción anatómica/fisiológica:

La artritis consiste en la inflamación de una o más articulaciones. Esta inflamación puede ser generada por diversos factores, por ejemplo, se puede deber a una enfermedad autoinmunitaria, fractura ósea, desgaste y deterioro de las articulaciones, o infección [1]. Existen diversos tipos de artritis, algunos de los más comunes son artritis reumatoide, gota, osteoartritis, artritis psoriásica y artritis reactiva [2]. Una de las más comunes es la artritis reumatoide, la cual es una enfermedad autoinmunitaria en la que se producen citocinas, quimiocinas y metaloproteasas que lesionan las articulaciones [3].

2. Factores y análisis de la enfermedad

Factores de riesgo principales:

Uno de los factores de riesgo principales de la artritis puede ser la obesidad y el sobrepeso, ya que este peso extra genera una tensión mayor sobre las articulaciones lo cual aumenta la probabilidad de un desgaste que conlleve a una inflamación de las mismas. Otro de los factores de riesgo es fumar, ya que esto puede dificultar la actividad física la cual es esencial para poder controlar los síntomas. Ciertas enfermedades como la enfermedad de Lyme, la infección por estafilococo y la gonorrea también pueden aumentar el riesgo de padecer artritis [4].

Manifestaciones clínicas más relevantes:

Algunos de los síntomas que presentan comúnmente los pacientes con artritis son dolor, enrojecimiento, calor e hinchazón en las articulaciones. En ciertos casos también se puede llegar a la deformación de las articulaciones y se reduce la capacidad de movimiento de las articulaciones [2].

Impacto funcional en la vida diaria:

La artritis, al inflamar las articulaciones, aumenta la rigidez y genera dolor en los movimientos que realiza la persona, lo cual dificulta el realizar actividades de la vida cotidiana que requieran movimiento. Algunas de las actividades que se pueden ver afectadas por esta enfermedad son el caminar, vestirse, subir escaleras [5].

3. Prevención, diagnóstico, tratamiento y monitoreo

Prevención:

Para prevenir la artritis es recomendable mantener un peso saludable y hacer ejercicio de bajo impacto frecuentemente. También es importante mantener una dieta saludable baja en azúcares y rica en ácidos grasos omega-3 y bastantes frutas y verduras, ya que estas contienen vitaminas y minerales importantes. Además, se recomienda no fumar para evitar problemas para realizar ejercicio. Para prevenir la artritis, específicamente la osteoartritis, también es importante evitar realizar movimientos excesivos y repetitivos [1].

Diagnóstico:

La artritis se diagnostica mediante la evaluación de los síntomas, un examen físico y análisis de sangre realizados al paciente con el fin de saber si posee los anticuerpos que generan esta enfermedad. Además, para poder ver el daño de la articulación se realiza una radiografía, tomografía computarizada del cuerpo completo, resonancia magnética nuclear musculoesquelética (RMN) y ultrasonido musculoesquelético [6].

Tratamiento:

Para tratar esta enfermedad se hace uso de diversas estrategias. Por ejemplo, se recomienda realizar actividad física aeróbica de bajo impacto y realizar ejercicios de flexibilidad. Además, se sugiere hidroterapia, masajes y colocar hielo o una fuente de calor sobre el área de la articulación afectada. También, por lo general se usan medicamentos que reducen el dolor, como el acetaminofeno, y que se encargan de la desinflamación de la zona afectada, como la aspirina, el ibuprofeno o el naproxeno [1].

Monitoreo:

Para poder monitorear la artritis se realizan evaluaciones clínicas, exámenes de sangre y toma de imágenes médicas para poder evaluar el estado en el que se encuentra la articulación. Para la toma de imágenes médicas se pueden realizar radiografías, tomografía, resonancia magnética nuclear musculoesquelética o ultrasonido musculoesquelético [5].

4. Reflexión ingenieril

Para poder hacer un correcto monitoreo de la artritis se requiere mayormente el uso de imágenes médicas para poder conocer el estado en el que se encuentra la articulación afectada. Sin embargo, para poder conseguir estas imágenes se requiere del uso de equipos médicos que pueden ser de difícil acceso para una determinada población que no cuente con la cercanía o los recursos económicos necesarios para hacer uso de estos servicios de imágenes médicas.

5. Referencias:

[1] A.D.A.M. Medical Encyclopedia [Internet]. Johns Creek (GA): Ebix, Inc., A.D.A.M.; c1997-2020. Arthritis; [Actualizado 2023 Diciembre 31]. Accedido el 25 de agosto de 2025. [En línea]. Disponible: https://medlineplus.gov/ency/article/001243.htm

[2] National Institute of Arthritis and Musculoskeletal and Skin Diseases. “NIAMS Health Information on Arthritis”. National Institute of Arthritis and Musculoskeletal and Skin Diseases. Accedido el 27 de agosto de 2025. [En línea]. Disponible: https://www.niams.nih.gov/es/informacion-de-salud/artritis

[3] K. Yaseen. “Artritis reumatoide - Trastornos de los tejidos musculoesquelético y conectivo - Manual MSD versión para profesionales”. Manual MSD versión para profesionales. Accedido el 28 de agosto de 2025. [En línea]. Disponible: https://www.msdmanuals.com/es/professional/trastornos-de-los-tejidos-musculoesquelético-y-conectivo/enfermedades-articulares/artritis-reumatoide#Etiología_v29657170_es

[4] U.S. Centers for disease control and prevention. “Arthritis Risk Factors”. Arthritis. Accedido el 25 de agosto de 2025. [En línea]. Disponible: https://www.cdc.gov/arthritis/risk-factors/index.html

[5] World Health Organization. “Artritis reumatoide”. World Health Organization (WHO). Accedido el 28 de agosto de 2025. [En línea]. Disponible: https://www.who.int/es/news-room/fact-sheets/detail/rheumatoid-arthritis

[6] Radiological Society of North America. “Artritis”. Radiologyinfo.org. Accedido el 28 de agosto de 2025. [En línea]. Disponible: https://www.radiologyinfo.org/es/info/arthritis

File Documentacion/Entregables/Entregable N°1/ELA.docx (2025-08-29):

Esclerosis lateral amiotrófica

Ficha de la enfermedad

- Nombre de la enfermedad: Esclerosis lateral amiotrófica (ELA)

- Sistema afectado: Sistema nervioso

- Breve descripción anatómica/fisiológica:

La esclerosis lateral amiotrófica(a partir de ahora llamada ELA) es una enfermedad degenerativa que afecta al sistema nervioso de forma irreparable, esta se caracteriza por afectar el correcto funcionamiento de las neuronas motoras, tanto de la corteza primaria superior, el tronco encefálico y la médula espinal, específicamente la asta anterior. [1]

La ELA provoca que estas neuronas empiecen a debilitarse y posteriormente morir, reduciendo su cantidad y eficiencia. En consecuencia, los músculos reciben menos señales que a su vez provoca su deterioro, genera movimientos involuntarios esporádicos y atrofia muscular. Conforme la enfermedad progresa, el usuario empieza a perder capacidades básicas tales como caminar, hablar e incluso respirar. Afectando no solo su vida diaria, sino su esperanza de vida. Aquellos que padecen esta enfermedad tienen una tasa de supervivencia de entre 3 a 5 años y suelen fallecer debido a las dificultades para respirar [1], [2].

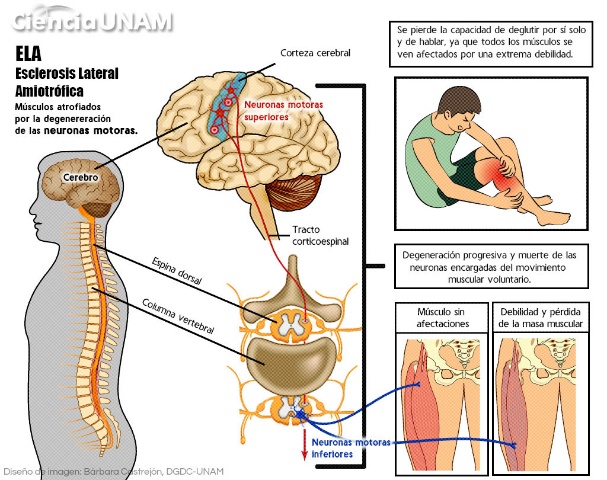
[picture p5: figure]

Fig. 1. Zonas afectadas por la ELA [3].

El principal problema de está enfermedad es que solo se han hallado motivos muy generales de su aparición, por lo que cualquier persona es propensa a contraer esta enfermedad.

Factores y análisis de la enfermedad

- Factores de riesgo principales:

Actualmente el ELA se caracteriza por ser una enfermedad de naturaleza principalmente esporádica. Unos de los factores de riesgo son una baja tasa de incidencia del 10 % en pacientes cuyos familiares de primer o segundo grado padecieron la enfermedad, una mayor incidencia en el sexo masculino, la edad alrededor de 55 a 75 años y por mutaciones en ciertos genes.

También hay otros posibles factores de riesgo como el tabaquismo, principalmente en mujeres posterior a la menopausia, campos electromagnéticos, exposición a toxinas o contaminación y una vida con mucho esfuerzo físico, actualmente se tiene considerable evidencia de estos, sin embargo, no se han confirmado al 100% que haya una relación entre estos. [2]

- Manifestaciones clínicas más relevantes:

Entre los principales síntomas están los movimientos involuntarios y espasmos, estos siendo usualmente en los hombros, extremidades y lengua. También se empiezan a presentar ciertas dificultades para masticar y tragar la comida, así como debilidad en las extremidades y hasta ligeros cambios en el comportamiento del usuario; los movimientos involuntarios también incluyen llanto, risas, gesticulación de palabras sin sentido y ruidos. [1], [4]

- Impacto funcional en la vida diaria:

Padecer ELA conforme la enfermedad progresa genera mayores impedimentos en la vida del paciente. Como los movimientos involuntarios que generan dificultad para gesticular en algunos casos, además de dificultades para caminar y sujetar objetos, debido a la debilidad de los músculos, se complica hacer cualquier actividad que requiera fuerza física. Finalmente, las dificultades para ingerir alimentos, para respirar y la pérdida de movilidad del usuario. [4]

3. Prevención, diagnóstico, tratamiento y monitoreo:

- Prevención:

Hoy en día no existe forma de prevenir esta enfermedad, debido a la falta de factores de riesgo claros que puedan contribuir con un indicativo de donde proviene. [2]

- Diagnóstico.

Existen varias formas de obtener un diagnóstico, entre las principales está la electromiografía, la cual analiza la actividad eléctrica de los músculos para determinar anormalidades y se realiza en conjunto con un estudio de conducción nerviosa para analizar los impulsos que envían los nervios, a través de estudios de sangre y orina, y a través de resonancia magnética entre otros procedimientos. Sin embargo, es difícil de detectar debido a la cantidad de afecciones que la imitan. [5], [6]

- Tratamiento (farmacológico, quirúrgico, rehabilitación).

La ELA no presenta cura hoy en día, solo existen tratamientos y fármacos que ayudan al alivio de los síntomas, para retrasar el progreso de la enfermedad y mejorar lo máximo posible la calidad de vida del paciente. Los fármacos que se usan son el Riluzol y la Edaravona , medicamento que se toma por vía oral que prolonga la esperanza de vida del paciente, sin embargo, este presenta efectos secundarios varios. En caso la ELA haya progresado al punto de dificultar el habla, la movilidad y la respiración, existen algunas terapias que ayudan a regular estas dificultades. [6]

- Monitoreo (ej. seguimiento clínico, pruebas periódicas).

Para asegurar la mayor tasa de supervivencia, se requiere de un monitoreo de la función respiratoria, además de monitoreos de la fuerza de los músculos y la funcionalidad del cuerpo. Un posible método es a través de los acelerómetros incluidos en los celulares, para analizar la movilidad del usuario y a partir de esta información estimar el cambio en los niveles de ALSFRS-RSE. [7]

4. Reflexión ingenieril:

Los pacientes que padecen ELA tienen como mayores problemas la dificultad para comunicarse, principalmente cuando la enfermedad ya ha avanzado, y la perdida de movilidad. La falta de esta no solo los limita físicamente, sino que la imposibilidad de poder hacer cosas por ti mismo, también afecta de manera psicológica al usuario. Ya que en una etapa avanzada estos dependen en mayor escala de otras personas para hacer actividades cotidianas. En este caso un dispositivo biomédico que ayude al paciente en su día a día es clave para reducir el riesgo de daños psicológicos.

[1]

“Amyotrophic Lateral Sclerosis (ALS) | National Institute of Neurological Disorders and Stroke”. Accedido: 27 de agosto de 2025. [En línea]. Disponible en: https://www.ninds.nih.gov/health-information/disorders/amyotrophic-lateral-sclerosis-als

[2]

C. Ingre, P. M. Roos, F. Piehl, F. Kamel, y F. Fang, “Risk factors for amyotrophic lateral sclerosis”, Clin Epidemiol, vol. 7, pp. 181–193, feb. 2015, doi: 10.2147/CLEP.S37505 (https://doi.org/10.2147/CLEP.S37505).

[3]

D. G. C. Salvador Ernesto Núñez Flores, Roberto Ramírez García, Julio César Romero, «Vivir con Esclerosis Lateral Amiotrófica», Ciencia UNAM. Accedido: 27 de agosto de 2025. [En línea]. Disponible en: https://ciencia.unam.mx/leer/846/-sera-posible-detener-el-avance-de-la-esclerosis-lateral-amiotrofica-

[4]

“Esclerosis lateral amiotrófica (ELA): MedlinePlus enciclopedia médica”. Accedido: 28 de agosto de 2025. [En línea]. Disponible en: https://medlineplus.gov/spanish/ency/article/000688.htm

[5]

“Esclerosis lateral amiotrófica - Diagnóstico y tratamiento - Mayo Clinic”. Accedido: 27 de agosto de 2025. [En línea]. Disponible en: https://www.mayoclinic.org/es/diseases-conditions/amyotrophic-lateral-sclerosis/diagnosis-treatment/drc-20354027

[6]

“El diagnóstico de ELA”, ALSA.org. Accedido: 2 de agosto de 2025. [En línea]. Disponible en: http://www.alsa.org/en-espanol/el-diagnstico-de-ela.html

[7]

M. Karas et al., “Tracking amyotrophic lateral sclerosis disease progression using passively collected smartphone sensor data”, Ann Clin Transl Neurol, vol. 11, no 6, pp. 1380–1392, jun. 2024, doi: 10.1002/acn3.52050 (https://doi.org/10.1002/acn3.52050).

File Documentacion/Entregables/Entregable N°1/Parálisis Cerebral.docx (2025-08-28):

1. Ficha de la enfermedad

La parálisis cerebral (PC) es un trastorno neurológico crónico y no progresivo, causado por una lesión en el cerebro en desarrollo, que afecta el movimiento, la postura y la coordinación. De acuerdo con la Organización Mundial de la Salud [1] y los Centros para el Control y Prevención de Enfermedades [3], se trata de una de las principales causas de discapacidad física en la infancia, con una prevalencia estimada de 1,5 a 4 casos por cada 1.000 nacidos vivos [1], [3]. Además de la alteración motora primaria, la PC suele acompañarse de comorbilidades como dificultades sensoriales, epilepsia, dolor crónico, trastornos de conducta, problemas musculoesqueléticos y limitaciones en la comunicación, lo que convierte a esta condición en un síndrome heterogéneo de amplio impacto en la vida del paciente y su entorno [1], [2].

Existen distintos tipos clínicos de PC, clasificados según la alteración predominante del tono y el movimiento:

- Espástica: Representa alrededor del 80% de los casos. Se caracteriza por rigidez muscular, reflejos exagerados y dificultad para realizar movimientos voluntarios coordinados.
- Discinética: Produce movimientos involuntarios, lentos o bruscos, que suelen afectar cara, lengua y extremidades, dificultando el habla y la alimentación.
- Atáxica: Menos frecuente, se manifiesta con problemas de equilibrio, temblores y falta de coordinación en movimientos finos.
- Mixta: Combinación de las anteriores, habitualmente espástica-discinética.

Las características clínicas varían en severidad, desde formas leves que permiten deambulación independiente, hasta cuadros graves que requieren asistencia para casi todas las actividades de la vida diaria. De acuerdo con el CDC [3], alrededor del 41% de los niños con PC tienen una limitación severa para caminar, y más del 30% presentan dificultades significativas en la comunicación oral. En este sentido, la parálisis cerebral no debe entenderse únicamente como una condición motora, sino como un trastorno complejo que involucra aspectos neurológicos, musculoesqueléticos, sensoriales y comunicativos, lo que exige un abordaje interdisciplinario [7].

2. Factores y análisis de la enfermedad

La etiología de la parálisis cerebral es multifactorial. Los factores de riesgo más reconocidos incluyen la prematuridad, la restricción del crecimiento intrauterino, infecciones congénitas, hemorragia intraventricular y complicaciones durante el parto como hipoxia o asfixia neonatal [4], [9]. Asimismo, estudios recientes señalan que hasta un 20% de los casos pueden estar relacionados con variantes genéticas, lo que explica la presencia de PC en familias con antecedentes neurológicos similares [10].

El análisis clínico requiere considerar tanto los antecedentes prenatales y perinatales como el desarrollo motor temprano. El retraso en la adquisición de hitos motores —como sostener la cabeza, sentarse o caminar— constituye una de las señales más tempranas de alerta [5]. La historia familiar también es clave, ya que orienta hacia posibles causas genéticas o enfermedades que simulan PC [10].

Las manifestaciones clínicas dependen del tipo de PC: la espástica genera rigidez y movimientos dolorosos; la discinética se asocia a movimientos incontrolables y dificultades oromotoras; la atáxica compromete el equilibrio y la marcha. La mayoría de los pacientes presentan formas mixtas, lo que incrementa la complejidad del manejo [2].

Desde una perspectiva funcional, la PC afecta significativamente la vida diaria. Según la OMS [1], [8], los niños con PC tienen menor independencia en actividades básicas como alimentarse, vestirse y movilizarse. Esta dependencia se incrementa en casos con limitaciones de comunicación, lo que repercute en la socialización y la integración escolar. Estudios de participación social [6], [7] han demostrado que las dificultades en el habla y el lenguaje son determinantes para la inclusión educativa y el desarrollo emocional, y que la intervención temprana es clave para reducir las barreras comunicativas.

En resumen, la PC no solo compromete el control motor, sino que también limita la autonomía y la interacción social, lo cual incrementa la carga familiar y condiciona el bienestar del paciente a largo plazo [7].

3. Diagnóstico y Tratamiento (Rehabilitación)

El diagnóstico de la parálisis cerebral (PC) es principalmente clínico y se basa en la identificación de un trastorno motor no progresivo en la infancia. La evaluación requiere una anamnesis detallada sobre antecedentes prenatales, perinatales y del desarrollo, así como la identificación de comorbilidades frecuentes [1], [3], [5]. Entre los métodos complementarios, la resonancia magnética cerebral es la técnica de imagen más recomendada, ya que permite detectar con alta sensibilidad lesiones como leucomalacia periventricular, malformaciones corticales y secuelas hipóxico-isquémicas, superando en especificidad a la tomografía computarizada [2], [9]. El cribado del desarrollo motor en lactantes, junto con la identificación de retrasos en hitos como sostener la cabeza o caminar, son herramientas clave para la detección temprana [4], [6].

El tratamiento de la PC es multidisciplinario y busca optimizar la funcionalidad y la calidad de vida. La fisioterapia y terapia ocupacional son la base de la rehabilitación motora, orientadas a mejorar fuerza, coordinación y movilidad [1], [3]. La terapia del habla aborda tanto la comunicación como la deglución, mientras que las intervenciones farmacológicas (por ejemplo, toxina botulínica para la espasticidad) y quirúrgicas (como rizotomía dorsal selectiva) se aplican en casos severos [2], [7].

En los últimos años, han surgido enfoques innovadores basados en la neuromodulación. La estimulación transcraneal de corriente directa (tDCS) y la estimulación magnética transcraneal (TMS) han demostrado mejorar el control motor y el lenguaje en ensayos clínicos, al modular la excitabilidad cortical y potenciar los efectos de la terapia física y del habla [10]. Estudios recientes reportan mejoras en la marcha y en la producción del habla tras la combinación de estas técnicas con programas de entrenamiento conductual, lo que subraya su potencial como complemento a la rehabilitación convencional [2], [10].

En conjunto, el abordaje diagnóstico y terapéutico de la PC requiere integrar tanto herramientas clínicas y de imagen como terapias tradicionales y emergentes. Este enfoque integral permite atender no solo las alteraciones motoras, sino también las limitaciones en comunicación, autonomía e inclusión social [3], [7], [9].

4. Reflexión Ingenieril

Se evidencia limitadas investigaciones de las PC enfocadas a dificultades en la comunicación, debido a que se enfocan principalmente a las manifestaciones clínicas motoras. Se conoce las limitaciones en entornos sociales y educacionales que se presentan a los usuarios y se evidencia la necesidad de herramientas de comunicación alternativa mejoradas debido a las limitaciones en los sistemas aumentativos y alternativos para una comunicación de lenguaje complejo, para mejorar la calidad de vida de las personas con parálisis cerebral [4], [6].

Referencias (IEEE)

[1] National Center for Biotechnology Information, “Cerebral Palsy,” StatPearls, 2023. [Online]. Available: https://www.ncbi.nlm.nih.gov/books/NBK538147/

[2] M. Ashwal et al., “Practice guideline: Diagnostic assessment of the child with cerebral palsy,” Neurology, vol. 95, no. 20, pp. 917–929, 2021. [Online]. Available: https://pubmed.ncbi.nlm.nih.gov/32053326

[3] Centers for Disease Control and Prevention (CDC), “Cerebral Palsy,” 2024. [Online]. Available: https://www.cdc.gov/cerebral-palsy/about/index.html

[4] C. De la Iglesia, “Factores de riesgo perinatales en la parálisis cerebral infantil,” Revista de Investigación en Educación, no. 0, pp. 117–133, 2015. [Online]. Available: https://revistas.udc.es/index.php/reipe/article/view/reipe.2015.0.09.642

[5] National Center for Biotechnology Information, “Cerebral Palsy – Overview,” StatPearls, 2023. [Online]. Available: https://www.ncbi.nlm.nih.gov/books/NBK538147/

[6] J. Pousada et al., “Lenguaje y comunicación en niños con parálisis cerebral,” CORE, 2020. [Online]. Available: https://core.ac.uk/download/pdf/539311570.pdf

[7] A. Bolaños-Roldán et al., “Calidad de vida relacionada con características sociodemográficas y clínicas en niños con parálisis cerebral,” Duazary, vol. 17, no. 2, pp. 23–34, 2020. [Online]. Available: https://www.redalyc.org/journal/5121/512170346003/512170346003.pdf

[8] World Health Organization, “Rehabilitation,” WHO, 2023. [Online]. Available: https://www.who.int/news-room/fact-sheets/detail/rehabilitation

[9] American Academy of Family Physicians (AAFP), “Cerebral Palsy: An Overview,” American Family Physician, vol. 101, no. 4, pp. 213–222, 2020. [Online]. Available: https://www.aafp.org/pubs/afp/issues/2020/0215/p213.html#afp20200215p213-b3

[10] J. C. Lima et al., “Transcranial direct current stimulation associated with motor and speech training in cerebral palsy: Case studies and perspectives,” Neurorehabilitation and Neural Repair, vol. 36, no. 4, pp. 245–256, 2022. [Online]. Available: https://pubmed.ncbi.nlm.nih.gov/35248256

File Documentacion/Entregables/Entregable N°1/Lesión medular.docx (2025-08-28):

Lesión medular

1. Ficha de la enfermedad

La Lesión de la Medula Espinal (LME) es un daño realizado en el conjunto de grupos de nervios y fibras nerviosas que interactúan con las señales que procesa el cerebro. La medula espinal toma dimensiones desde la parte inferior del cerebro y se extiende hasta la parte inferior de la espalda [1]. La lesión en la medula espinal al estar relacionada al sistema nervioso una lesión en esta provoca daños a niveles neurológicos, los cuales afectan la integridad física y la calidad de vida de la persona que tuvieron el traumatismo. [2] Las lesiones causadas en la medula pueden causar parálisis. Por su parte, lesiones en la parte alta de la médula afectan una mayor parte del cuerpo junto todas las extremidades (tetraplejía o cuadriplejía). Mientras, que las lesiones en la parte baja de la médula pueden solo afectar la parte inferior del cuerpo y las piernas (paraplejía)

La médula espinal es una estructura blanda y cilíndrica formada por células nerviosas, gliales, fibras nerviosas (axones) y vasos sanguíneos. Su función principal es transmitir información entre el cerebro y el resto del cuerpo, además de coordinar movimientos complejos como la respiración y la marcha.

Se extiende desde el cerebro hasta la parte baja de la espalda, protegida por vértebras, meninges y líquido cefalorraquídeo, que la resguardan de impactos.

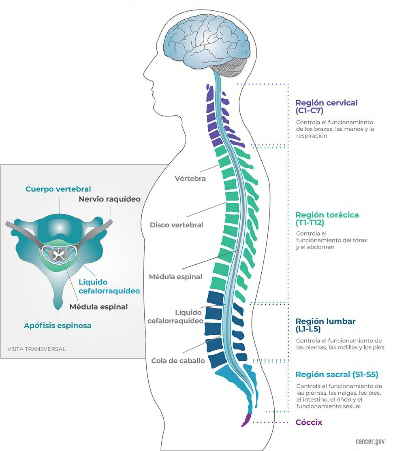
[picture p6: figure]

Fig. 1 [] https://www.cancer.gov/rare-brain-spine-tumor/espanol/tumores/anatomia

En su interior se distinguen dos componentes principales:

Materia gris, compuesta por cuerpos celulares que procesan y transmiten información localmente.

Materia blanca, formada por axones (muchos recubiertos de mielina) que permiten la comunicación a larga distancia entre neuronas. [1]

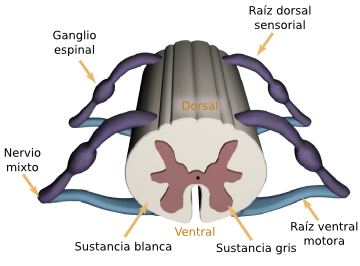
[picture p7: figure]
Médula espinal: Regiones

Fig. 2 [] https://mmegias.webs.uvigo.es/2-organos-a/guiada_o_a_01medula.php

2. Factores y análisis de la enfermedad

Según Steinemann et al, los principales traumatismos raquimedulares tuvieron una principal incidencia a causa de lesiones relacionadas a caídas, seguidas de accidentes automovilísticos, incluyendo la colisión con objetos o personas.

Por otro lado, el estudio hecho en bélgica por Widaele, nos muestra prevalencia que varia entre 223 a 755 por millón de habitantes.

Los daños originados en la médula tienen una relación directa con la parálisis, perdida motora del cuerpo, estas se desenvuelven principalmente en las extremidades del cuerpo, según una página web se señala que en Estados Unidos

291 000 sufren lesiones medulares, el 39.5% de los lesionados se encuentran en condición de paraplejía y el 59.9% en tetraplejía. [3]

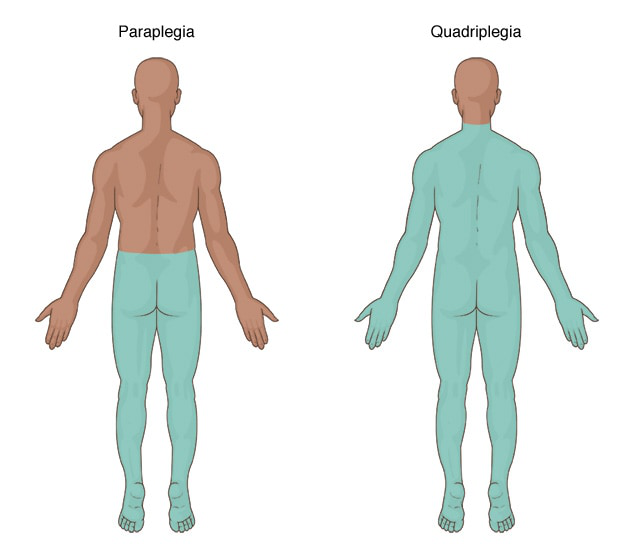
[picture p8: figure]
Lesión de la médula espinal - Síntomas y causas - Mayo Clinic

Fig 3. [] https://www.mayoclinic.org/es/diseases-conditions/spinal-cord-injury/symptoms-causes/syc-20377890

Por otro lado, los daños de origen no traumático relacionadas a los trastornos vasculares, dolencias degenerativas de la columna vertebral, tumores, infecciones bacterianas y enfermedades inflamatorias y autoinmunes. Este tipo de traumatismo es llamado lesión primaria y es generada por la energía del trauma lo que provoca fallas biomecánicas de la estructura que soporta la columna, seguida de lesiones secundarias que es la manifestación de fenómenos locales de isquemia, inflamación, hiper-excitabilidad neuronal y generación de radicales libres, para finalmente inducir a la mayor cantidad de muerte neuronal, que puede conducir a la perdida de sistema motor y sensitivo debajo de la lesión. [3]

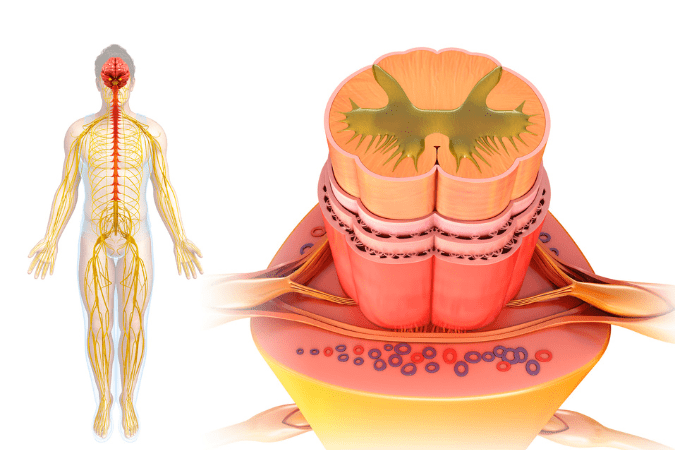
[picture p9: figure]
Lesión Medular: Niveles, causas y recuperación | Neurocirugía Madrid

Fig 4. [] https://neurocirugia.madrid/actualidad/lesion-medular-niveles-causas-y-recuperacion/

3. Prevención, diagnóstico, tratamiento y monitoreo

Prevención

La principal causa de LME radica en accidentes de origen traumático, como por ejemplo son los accidentes automovilísticos, laborales y caídas. Es por ello, que la forma más oportuna de prevenir lesiones es desarrollar una cultura de prevención que pueda ser consciente de los riesgos que rodean el entorno en el que se vive. Mediante campañas de seguridad vehicular, en donde se busque prevalecer una conducción segura junto con el cuidado y mantenimiento de carreteras, se pueda reducir principalmente el índice de lesiones. Asu vez, también es necesario el aumento de medidas de seguridad en entornos labores que sean de alto riesgo [4].

Diagnostico

La tomografía computada (CT) permite obtener imágenes transversales de la columna para localizar lesiones y detectar complicaciones como hematomas. La resonancia magnética (MRI) ofrece una visión más precisa de tejidos blandos y ayuda a identificar hernias de disco y compresiones nerviosas. El mielograma, mediante la inyección de un contraste y posterior radiografía, resalta la médula espinal y las raíces nerviosas para detectar obstrucciones o compresiones. Los estudios neurofisiológicos, como los potenciales evocados somatosensoriales (SSEP) y la estimulación magnética, evalúan si las señales nerviosas atraviesan la médula de manera adecuada y permiten estimar el grado de compromiso neurológico. Finalmente, las radiografías simples de columna, aunque menos detalladas, son útiles para diagnosticar fracturas y daños en las vértebras. [5]

Tratamiento

Para el tratamiento a personas que han sufrido lesiones en la médula y perdido la sensibilidad motora en sus extremidades, se han desarrollado diversos métodos que permiten que estas personas puedan recuperar esta sensibilidad motriz o en muchos casos recibir un soporte externo que los ayude a realizar sus actividades diarias. La estimulación eléctrica desenvuelve un rol importante en los tratamientos de rehabilitación y regeneración, este proceso se lleva a cabo mediante la inducción de cambios neuroplásticos en la sinapsis de la medula espinal. La neuroplasticidad es el proceso por el cual los axones y la sinapsis se reacomodan y se adaptan al entorno [6]. Por otro lado, se cuenta con oxigenoterapia que se encuentra enfocada en la neurodesinflamación, el aumento de niveles de O2 a 3 ATA ayudan a minimizar la perdida neuronal [7]. Los exoesqueletos también forman parte de los tratamientos utilizados para ayudar a personas con parálisis, los cuales van desde primera generación (lokomat) segunda generación (ReWalk, Ekso, Soft Exosuit) y tercera generación (FourierX2) [8].

Monitoreo

El Monitoreo Neurofisiológico Intraoperatorio (MIO) es hoy el estándar en cirugías de columna por deformidades, traumatismos o patología degenerativa, especialmente cuando se requiere instrumentación o descompresión. Su aplicación es fundamental en lesiones cervicales, dado que permite detectar alteraciones en tiempo real y guiar maniobras quirúrgicas que influyen directamente en el pronóstico funcional. El MIO ofrece beneficios tanto en pacientes sin daño previo como en aquellos con déficits neurológicos parciales o severos, lo que refuerza su importancia en la práctica neuroquirúrgica actual. [9]

4. Reflexión ingenieril

La ingeniería biomédica ha permitido el desarrollo de diversas tecnologías que mejoran la calidad de vida de los pacientes con lesión de la médula espinal (LME). En el área de la movilidad, los exoesqueletos robóticos de distintas generaciones, junto con las sillas de ruedas con sistemas de control avanzado, los andadores y las grúas de transferencia, proporcionan apoyo para el desplazamiento y la realización de actividades cotidianas. En el diagnóstico y el monitoreo, equipos como la tomografía computada, la resonancia magnética y el Monitoreo Neurofisiológico Intraoperatorio (MIO) cumplen un papel fundamental al identificar lesiones y reducir riesgos durante cirugías complejas. En cuanto al tratamiento, técnicas como la estimulación eléctrica y la oxigenoterapia hiperbárica favorecen la recuperación funcional mediante procesos de neuroplasticidad y protección neuronal.

A pesar de estos avances, aún existen retos en el control de la lesión secundaria, la prevención de la inflamación y la muerte neuronal, así como en el acceso a tecnologías de rehabilitación. En este sentido, el desarrollo de programas de simulación digital y nuevas herramientas terapéuticas representa una oportunidad para personalizar tratamientos y optimizar resultados clínicos. De esta forma, la LME constituye un desafío tanto médico como ingenieril, donde la tecnología se convierte en un elemento decisivo para mejorar el pronóstico y la autonomía de los pacientes.

Referencias

[1] National Institute of Neurological Disorders and Stroke (NINDS), “Lesión de la médula espinal,” National Institutes of Health. [En línea]. Disponible en: https://www.ninds.nih.gov/es/health-information/disorders/lesion-de-la-medula-espinal. [Accedido: 28-ago-2025].

[2] “Lesión medular,” Biblioteca Virtual en Salud (BVS). [En línea]. Disponible en: https://pesquisa.bvsalud.org/portal/resource/pt/lil-639004. [Accedido: 28-ago-2025].

[3] J. F. Cañar Camacho, Factores de riesgo y prevalencia de la lesión medular en adultos: una revisión sistemática. Cuenca, Ecuador: Universidad Católica de Cuenca, 2023.

[4] M. A. Torres Alaminos, “Aspectos epidemiológicos de la lesión medular en el Hospital Nacional de Parapléjicos,” Enferm. Nefrol., vol. 12, no. 2, p. 122, 2018. [En línea]. Disponible en: http://scielo.isciii.es/scielo.php?script=sci_arttext&pid=S1988-348X2018000200002&lng=es&tlng=es. [Accedido: 28-ago-2025].

[5] Eunice Kennedy Shriver National Institute of Child Health and Human Development (NICHD), “Lesión de la médula espinal: diagnóstico,” NIH Español. [En línea]. Disponible en: https://espanol.nichd.nih.gov/salud/temas/spinalinjury/informacion/diagnostica. [Accedido: 28-ago-2025].

[6] M. D. Sunshine, V. E. Bindi, B. L. Nguyen, et al., “Oxygen therapy attenuates neuroinflammation after spinal cord injury,” J. Neuroinflammation, vol. 20, p. 303, 2023. doi: https://doi.org/10.1186/s12974-023-02985-6.

7] “Exoskeleton-Assisted Rehabilitation and Neuroplasticity in Spinal Cord Injury,” World Neurosurgery, vol. 185, pp. 45–54, 2024. doi: https://doi.org/10.1016/j.wneu.2024.01.167.

[8] B. A. Karamian, N. Siegel, B. Nourie, et al., “The role of electrical stimulation for rehabilitation and regeneration after spinal cord injury,” J. Orthop. Traumatol., vol. 23, p. 2, 2022. doi: https://doi.org/10.1186/s10195-021-00623-6.

[9] “Monitoreo neurofisiológico intraoperatorio en traumatismo raquimedular cervical y columna cervical compleja: Recomendaciones desde una visión dual basada en experiencia personal,” Rev. Chil. Neurocir., vol. 46, no. 1, pp. 21–30, Jul. 2020. doi: 10.36593/rev.chil.neurocir.v46i1.182.

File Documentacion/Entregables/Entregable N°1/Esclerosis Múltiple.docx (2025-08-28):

# Esclerosis Múltiple

## 1. Ficha de la enfermedad

La esclerosis múltiple es una enfermedad crónica del sistema nervioso que es producida cuando el sistema inmunológico ataca al encéfalo y la médula espinal al someter a las neuronas a un proceso de desmielinización. [1]

Anatomía y fisiología del sistema nervioso:

El sistema nervioso regula todos los procesos del organismo, este se encarga de llevar a cabo acciones voluntarias e involuntarias y relacionar al ser vivo con el medio externo. Está formado por todas las redes de tejido nervioso que lo conforman las células gliales y las neuronas, las cuales transmiten información mediante impulsos eléctricos.[2] Asimismo, el sistema nervioso se divide en Sistema nervioso central, el cual incluye al encéfalo; constituido por el cerebro, el cerebelo y el tallo encefálico; y la médula espinal y sistema nervioso periférico, el cual abarca los nervios salientes de la médula espinal al resto del cuerpo.[3]

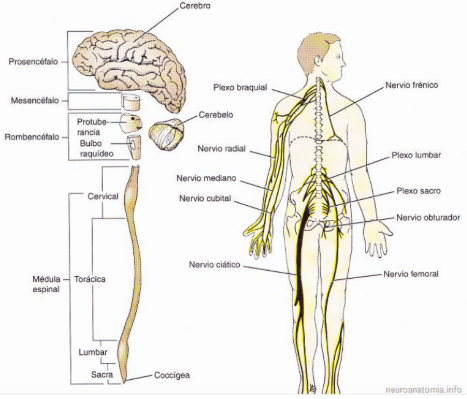
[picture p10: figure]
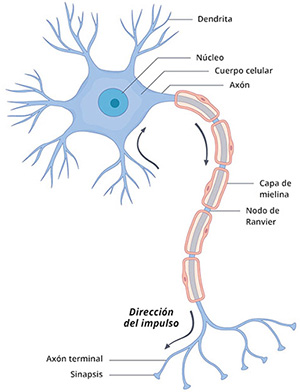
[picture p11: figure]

Fig 1. Sistema nervioso central y periférico del ser humano. [2] Fig 2. Neurona [4]

Las neuronas cuentan con un axón y dendritas, alrededor del primero se encuentra la capa o vaina de mielina, una mezcla de proteínas y ácidos grasos, cuya función es facilitar la comunicación entre neuronas al transmitir el impulso nervioso de forma mucho más rápida[5]. Por otro lado, las glías cumplen diversas funciones como los oligodendrocitos, los cuales producen mielina en el SNC[2].

Por otro lado, el sistema inmunitario cuenta con glóbulos blancos, que forman los linfocitos T y células B, así como otros órganos útiles para combatir infecciones y otras enfermedades[6]. La EM aparece por una activación de linfocitos T en la periferia del SNC. Esto les ordena a atravesar la barrera hematoencefálica, debilitarla para el ingreso de otros cuerpos inmunológicos, y empezar a atacar a la vaina de mielina y los axones.[7]

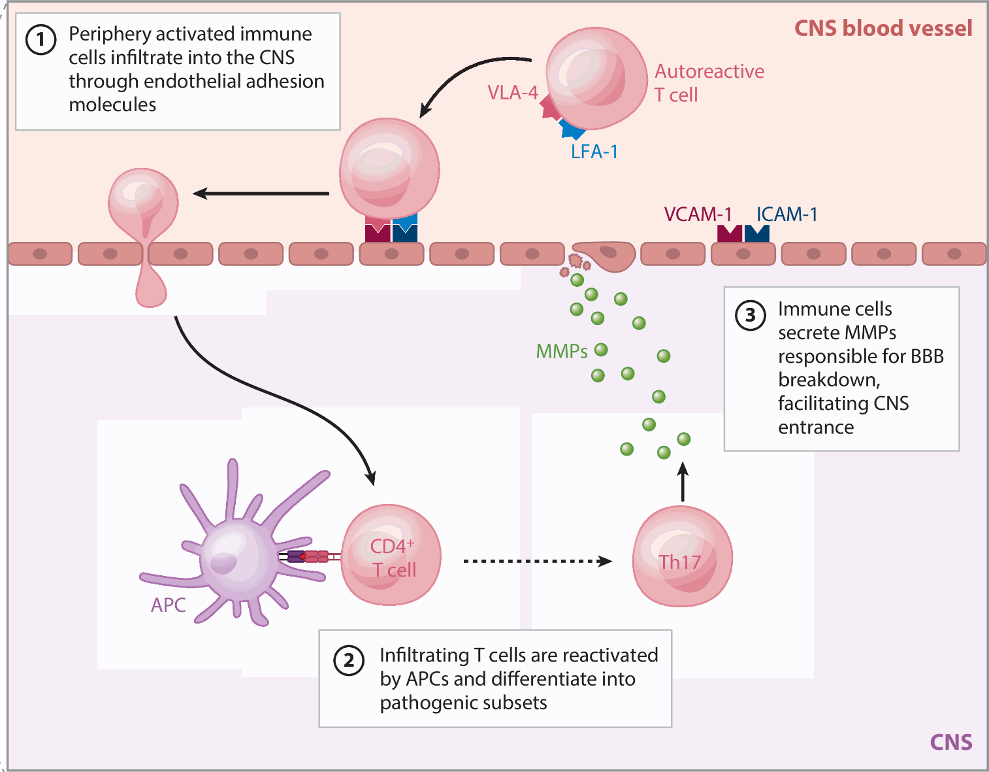
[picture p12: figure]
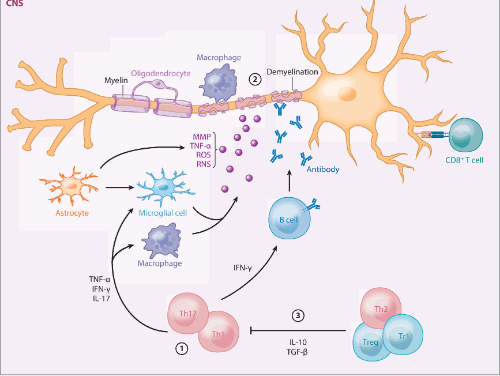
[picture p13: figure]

Fig 3. Ingreso de leucocitos T al SNC[7] Fig 4. Proceso de desmielinización en neurona [7]

2. Factores y análisis de la enfermedad

Factores de riesgo principales

La esclerosis múltiple presenta factores de riesgo tanto para el comienzo de esta, como para su progresión. En el caso de la aparición de la EM, se encuentran factores genéticos, como el antígeno de leucocito humano clase II, asimismo el tener infecciones previas de Herpes 6, Epstein-Barr virus, fumar, baja exposición al sol y bajo nivel de vitamina D u obesidad infantil/ adolescente conforman otros factores de riesgo. Asimismo, se encontró que el periodo entre la menarquía y la menopausia causa un ratio de 3:1 en riesgo de aparición de EM en mujeres. Por otro lado, factores dietéticos como alto consumo de grasas saturadas, bajo consumo de vegetales; grado de contaminación del aire por dióxido de nitrógeno y ozono; así como mantener las condiciones que vuelven al organismo propenso a desarrollar EM, pueden generar un mayor riesgo de progresión de la enfermedad[8].

Manifestaciones clínicas más relevantes

Esto puede desencadenar en varios síntomas como: problemas de visión, dificultad de movimiento (ataxia), debilidad muscular, falta de sensación en ciertas partes del cuerpo, fatiga, dificultad para pensar, pérdida de balance, depresión, problemas de función sexual o micción.[1], [9].

Esto se manifiesta según el tipo de EM. El más común es la EM remitente recurrente, el cual se caracteriza por tener recaídas con la aparición o agravamiento de los síntomas mencionados, pero con una mejora o desaparición del síntoma luego del episodio. Con el tiempo puede evolucionar a una EM progresiva secundaria, en la que las recaídas se vuelven menos frecuentes pero el paciente desarrolla un mayor grado de discapacidad. En caso el individuo presente EM progresiva primaria, presentará síntomas que empeorarán con el tiempo sin recaídas[9].

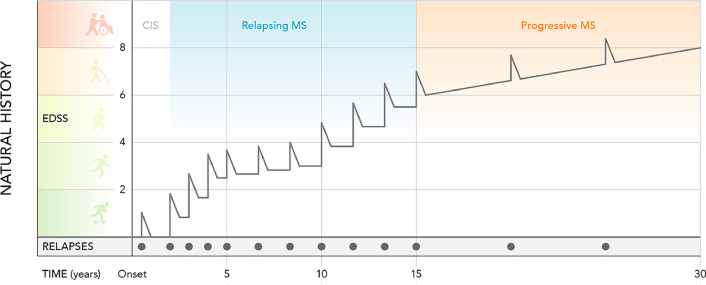
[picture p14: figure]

Fig 5. Escala de progresión de la EM en tiempo, recaídas e impacto en la funcionalidad del paciente [10]

Impacto funcional en la vida diaria

Los síntomas presentes juegan un rol importante en la calidad de vida del paciente. Tanto en el aspecto físico, al afectar la capacidad motora, sensorial y cognitiva, como en aspectos psicológicos, como la depresión y ansiedad, los cuales, de no ser tratados, pueden empeorar el manejo de la enfermedad[11], [12].

El grado de impacto funcional de la enfermedad varía según el grado de progresión de los síntomas, los cuales privan de independencia de forma parcial o completa a los pacientes. Como la capacidad de desplazarse e incrementar el riesgo de caerse, siendo que el 50%-70% llega a caerse en 6 meses, mientras que 30%-50% se cayó y se lesionó[13]. Asimismo, aspectos como la pérdida de visión, audición, parálisis o trastornos de habla serían otros perjuicios críticos en la calidad de vida del paciente[14].

3. Prevención, diagnóstico, tratamiento y monitoreo

Prevención

La patología de esta enfermedad es considerada rara y es posible estar expuesto a varios factores de riesgo y no llegar a padecer la enfermedad. En ese sentido, se da crucial importancia al estudio del pródromo de la enfermedad, el cual se define como la etapa temprana donde se manifiestan signos o síntomas leves de la enfermedad y se desarrolla de 5 a 10 años antes del comienzo de la enfermedad[15].

Por otro lado, es imperativo evitar los diversos factores de riesgo asociados al comienzo de la enfermedad, tales como buscar elevar los niveles de vitamina D y exposición al sol, evitar el consumo de tabaco. Por último, se considera necesario investigar más en desarrollos de vacunas contra el VEB al representar este uno de los factores más importantes en el desarrollo de EM [16].

Diagnóstico

La diagnosticación involucra una combinación de señales y síntomas, así como muestras radiográficas como imágenes resonancia magnética, la cual puede detectar procesos tempranos de desmielinización durante el pródromo de la enfermedad, y análisis de laboratorio, tales como análisis de bandas oligoclonales del líquido cefalorraquídeo para detectar concentraciones altas de inmunoglobulina producida por una regulación inefectiva de las células B[17], [18].

Por parte de síntomas sensoriales, se suelen realizar test para detectar una demora o complicación en la sensación visual, auditiva y de tacto. A la par, se le es solicitado al paciente datos que puedan indicar factores de riesgo para el comienzo de la enfermedad, especialmente el haberse contagiado con el VEB[10], [19].

Tratamiento

El tratamiento general más usado son las terapias modificadoras de la enfermedad, la cual consiste en una serie de fármacos, los cuales pueden venir en forma de pastillas, inyectables o infusiones cuya función es reducir la frecuencia de recaídas por la enfermedad y la progresión de discapacidad confirmada al promover la remielinización y brindar efectos neuroprotectores. Estos suelen recetarse según el tipo de EM que posea el paciente y su grado de progresión [20].

Asimismo, se brindan tratamientos especializados para cada síntoma de la EM, los cuales incluyen fisioterapias para problemas de marcha, estabilidad, espasmos, ataxia, fatiga; psicoterapia debido al alto riesgo de padecer de depresión y ansiedad; productos asistivos para la disfunción de control de vejiga. De igual forma, este tratamiento suele ser acompañado con diversos fármacos que ayudan a reducir el impacto de estos síntomas[10].

Monitoreo

Al tratarse de una enfermedad del SNC, las imágenes por RM son de suma importancia para monitorear deterioros en las redes cerebrales y atrofia de materia gris para evaluar la progresión de las dificultades cognitivas y, con ello, evaluar la continuidad o cambio de la medicación existente. Asimismo, se utiliza el Test de modalidades de Símbolos y Dígitos (SDMT) para evaluar la velocidad de procesamiento cognitivo y memoria[21].

Por otro lado, [22] plantea el prototipo de un gemelo digital para cada paciente con EM, la cual, con ayuda de IA y big data, posee un gran potencial para mejorar la precisión en la personalización de las terapias modificadoras de la enfermedad, al permitir visualizar los resultados de progresión de la enfermedad con anterioridad.

4. Reflexión ingenieril

Existen varias tecnologías que permiten al paciente mejorar su calidad de vida en diversos aspectos. Por el lado de la movilidad, equipos como andadores envolventes o con apoyos de codo; bipedestadores estáticos o dinámicos; sillas de ruedas con controles de movimiento, control cefálico para mantener una cabeza erguida al momento de desplazarse. Es importante el uso de grúas fijas y móviles para realizar cualquier tipo de traslado como entrar y descender de un automóvil, entrar a la ducha o a la cama. Esto es ayudado con arneses, tablas y discos de transferencias[23].

Por otro, la utilización de ortesis de pie o pie-tobillo fueron útiles suelen incrementar ligeramente la velocidad media, sin embargo, no suele ser un valor significativo. La AFO permite una flexión, aunque limitada, de la planta del pie, lo cual contribuye a mejorar la estabilidad y reducir caídas[24]. Por otro lado, la modificación de zapatos con una suela más grande y amortiguación adicional permite un mejor control del balance corporal al tener una mayor superficie de contacto con el suelo[25].

Asimismo, la utilización de equipos tecnológicos como resonadores magnéticos forma parte crucial para el diagnóstico y monitoreo constante del paciente, así como equipos de radioterapia para tratar síntomas paroxismales y equipos de ayuda urinaria [10].

Existen varios aspectos que necesitan una mayor investigación, como la causa misma de la enfermedad y el análisis de veracidad de diversos factores de riesgo para el comienzo y progresión de la enfermedad, como desbalances hormonales, ingesta alta de pescados o aspectos epigenéticos en general[8]. Asimismo, el desarrollo a gran escala de programas como el gemelo digital serán grandes avances para el mejoramiento de tratamientos para la esclerosis múltiple[22].
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

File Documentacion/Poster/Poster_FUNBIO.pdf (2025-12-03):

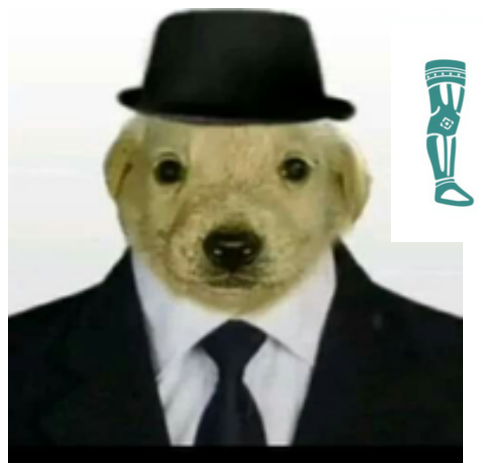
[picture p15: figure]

## Conclusiones y recomendaciones

### Traccion:

Uso del soporte
personalizado para el
paciente.

# KAFO-PULLEY ASSIST

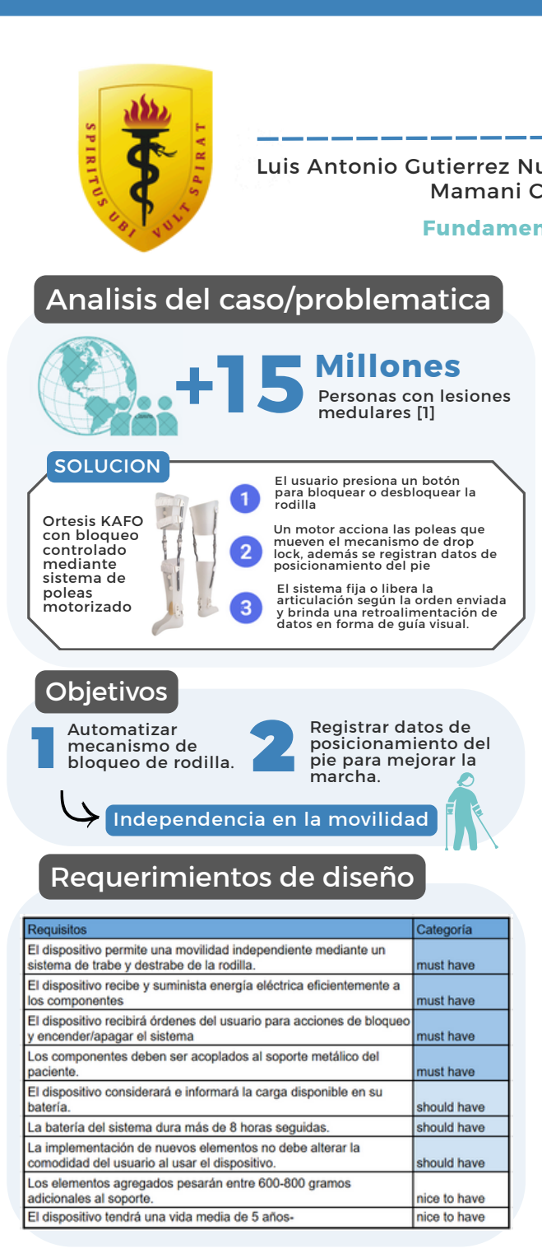
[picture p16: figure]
Analisis del caso/problematica; Objetivos; Requerimientos de diseño; Millones; Personas con lesiones medulares [1]; Automatizar mecanismo de bloqueo de rodilla.; Registrar datos de posicionamiento del pie para mejorar la marcha.; SOLUCION; Independencia en la movilidad; Ortesis KAFO con bloqueo controlado mediante sistema de poleas motorizado; El usuario presiona un botón para bloquear o desbloquear la rodilla; Un motor acciona las poleas que mueven el mecanismo de drop lock, además se registran datos de posicionamiento del pie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

Luis Antonio Gutierrez Nuñez; Xavier Alexis Hernandez Jeronimo; Jonatan Esteban Huiñapi Huaman; Alexandra Milagros Mamani Casas; Mariam Michelle Morocho Bustamante; Ricardo Sebastián Murillo Sedano.

### Fundamentos de Biodiseño 2025-2, Ingeniería Biomedica, Facultad de Ciencias e Ingenieria

Diseño/Prototipado | Resultados

## REFERENCIAS:

### Bocetos:

### Modelado 3D:

## Resultados software:

Retroalimenta del estado de batería y posicionamiento del pie Usuario tiene acceso a los cambios de modo y encendido/apagado del sistema en general.

## Resultados hardware:

Se puede alternar entre modos sin apoyo de terceros
Dispositivo no invasivo
Peso menor de 600 gramos y
Sin inconvenientes en la comodidad del usuario.

### Pruebas de funcionamiento:

### Limitaciones

Diagrama esquemático

Manufactura de
impresión 3D

Caja de componentes
principales ensamblada

Implementación
de motores

Ensamble

Se lograron los objetivos planteados de las funciones que debía cumplir el dispositivo. Se podría mejorar el dispositivo realizando una caja para el MPU que se acople mejor al pie. También se podría trabajar en disminuir el espacio de la caja y el peso de los componentes.

[1] Instituto Nacional de Rehabilitación enfatiza la importancia de proteger la médula espinal. Instituto Nacional de Rehabilitación -Perú, Dec. 13, 2023. [Online]. Available: https://www.gob.pe/institucion/inr/noticias/1240586-instituto-nacional-de-rehabilitacion-enfatiza-la-importancia-de-proteger-la-medula-espinal.
[2] International Perspectives on Spinal Cord Injury. World Health Organization, 2013. [Online]. Available:https://www.researchgate.net/publication/259496836_International_Perspectives_on_Spinal_Cord_Injury.

De la idea al
prototipo

Tiempo disponible
para realizar el
dispositivo.

# GRUPO 13 - Horario B403

Tener que acoplar los
elementos al soporte sin
realizar modificaciones
en este.

Forma de varillas
del soporte por las
que pasa el bloque.

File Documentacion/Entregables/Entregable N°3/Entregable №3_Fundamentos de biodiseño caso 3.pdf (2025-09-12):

Caso 3:

### 1. Caso de referencia (fuente secundaria)

El caso refiere a una mujer de 73 años de edad con obesidad y sin antecedentes médicos de interés. Tras una caída en las escaleras de su domicilio es trasladada al hospital local y es dada de alta con un collarín cervical. Después de 5 días se realiza una tomografía axial computarizada, en la cual se encuentra una subluxación C6-C7 y hundimiento del platillo superior de C7. Por lo cual es derivada al hospital universitario y Politécnico La Fe para obtener un diagnóstico más certero.

Posteriormente, la paciente es sometida a cirugía, con el fin de fijar C6-D1. Con lo cual, la paciente presentó considerables mejoras tanto en su nivel de lesión medular, pasando de C6 A.S.I.A B. a C6 A.S.I.A C., como en su estado general y también reduciendo el área de las zonas afectadas por hipoestesia.

### 2. Perfil funcional

Como diagnóstico principal se determinó una esguince cervical, sin embargo después de un par de días la paciente empezó a notar paresia de manera progresiva en su extremidades superiores e inferiores, por lo cual posteriormente volvió al hospital y el diagnóstico fue extendido a una subluxación C6-C7 con nivel de lesión medular C6 A.S.I.A B. Este se caracteriza por pérdida de la motricidad a partir de la zona afectada para el resto inferior del cuerpo, pero cuenta con la conservación de sensibilidad, la cual es disminuida por zonas de nivel C6 bilateral con algunas áreas de normoestesia parcheadas hasta segmentos sacros.

### 3. Mapa de actividades críticas. Describir al menos 3 actividades de cada
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

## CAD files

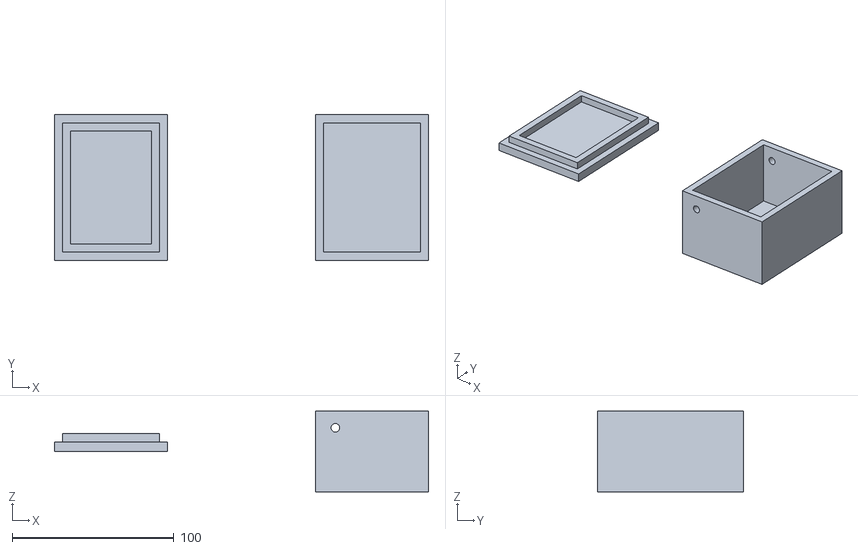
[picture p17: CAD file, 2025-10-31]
Documentacion/Entregables/Entregable N°9/built/Caja componentes muslo.stl
231.3 x 90.0 x 50.0

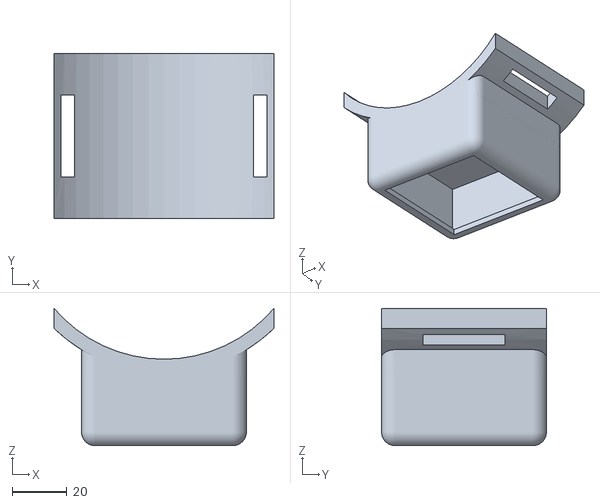
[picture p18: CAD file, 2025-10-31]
Documentacion/Entregables/Entregable N°9/built/Caja componentes.stl
80.0 x 60.0 x 50.0

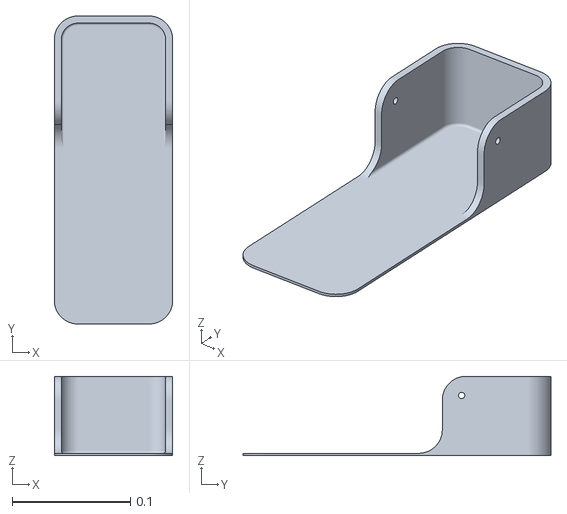
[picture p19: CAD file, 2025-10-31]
Documentacion/Entregables/Entregable N°9/built/Parte pie.stl
0.1 x 0.26 x 0.067

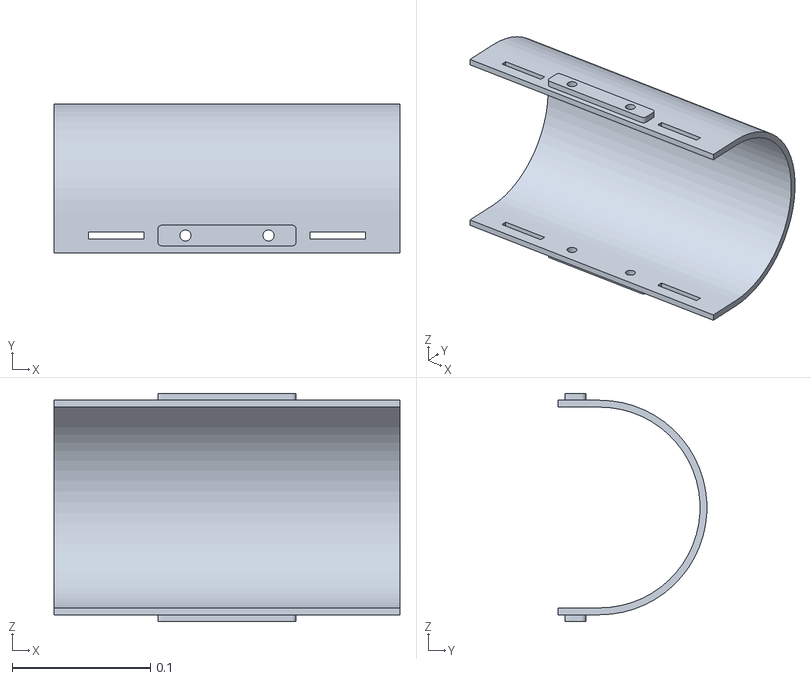
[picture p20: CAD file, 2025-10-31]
Documentacion/Entregables/Entregable N°9/built/Parte muslo.stl
0.25 x 0.107 x 0.165

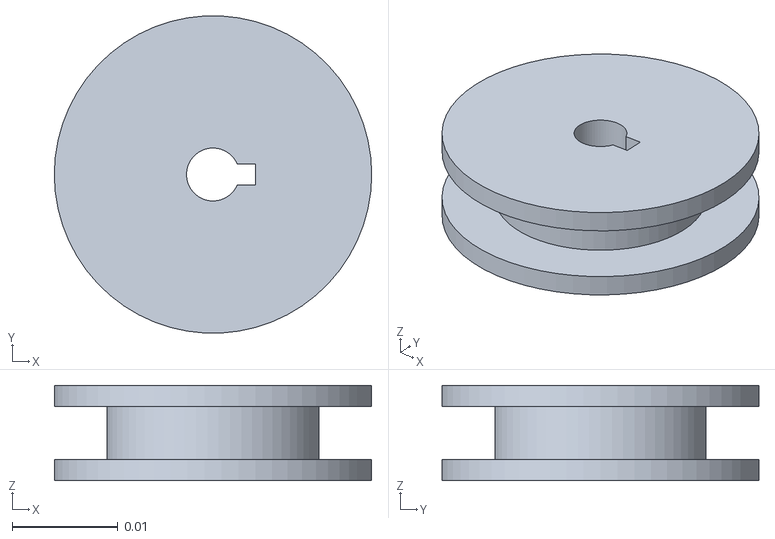
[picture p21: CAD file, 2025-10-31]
Documentacion/Entregables/Entregable N°9/built/Poleas pequeñas rueda - Part 1.stl
0.03 x 0.03 x 0.009

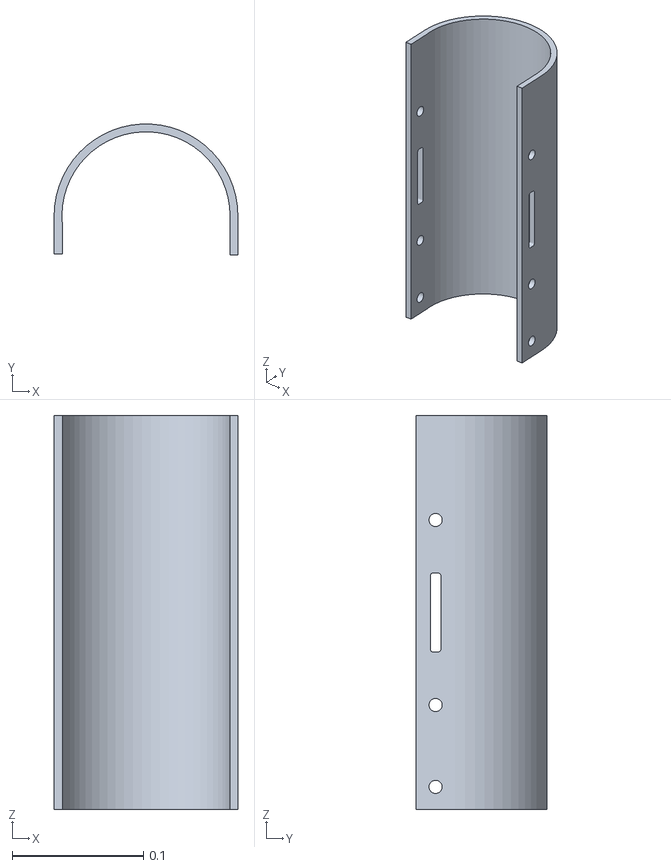
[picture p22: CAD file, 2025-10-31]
Documentacion/Entregables/Entregable N°9/built/Parte pantorrilla.stl
0.14 x 0.0996 x 0.3

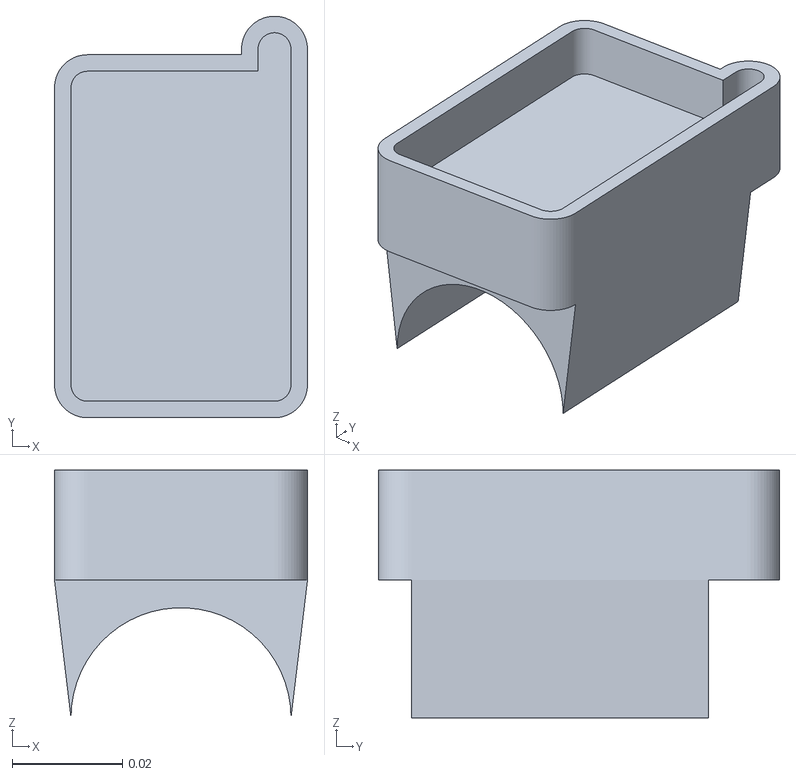
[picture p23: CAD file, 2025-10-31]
Documentacion/Entregables/Entregable N°9/built/Boton carcasa.stl
0.046 x 0.073 x 0.045

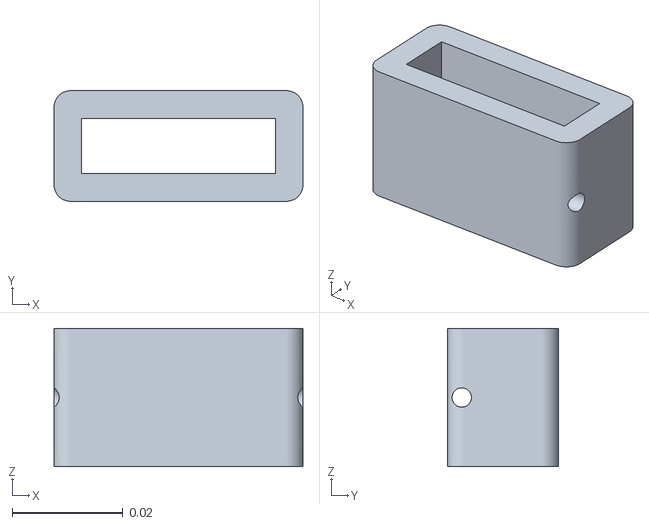
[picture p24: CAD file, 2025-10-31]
Documentacion/Entregables/Entregable N°9/built/Rodilla 2.stl
0.045 x 0.02 x 0.025

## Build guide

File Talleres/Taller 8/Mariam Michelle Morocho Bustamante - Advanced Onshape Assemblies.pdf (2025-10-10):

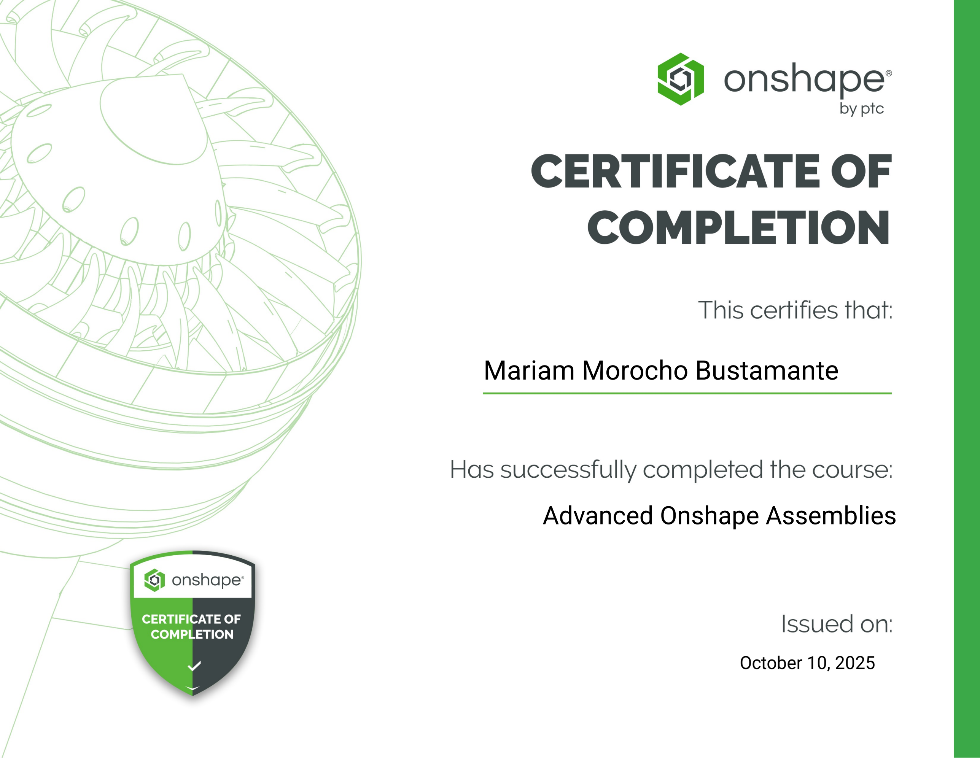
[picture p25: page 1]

Mariam Morocho Bustamante

Advanced Onshape Assemblies

October 10, 2025

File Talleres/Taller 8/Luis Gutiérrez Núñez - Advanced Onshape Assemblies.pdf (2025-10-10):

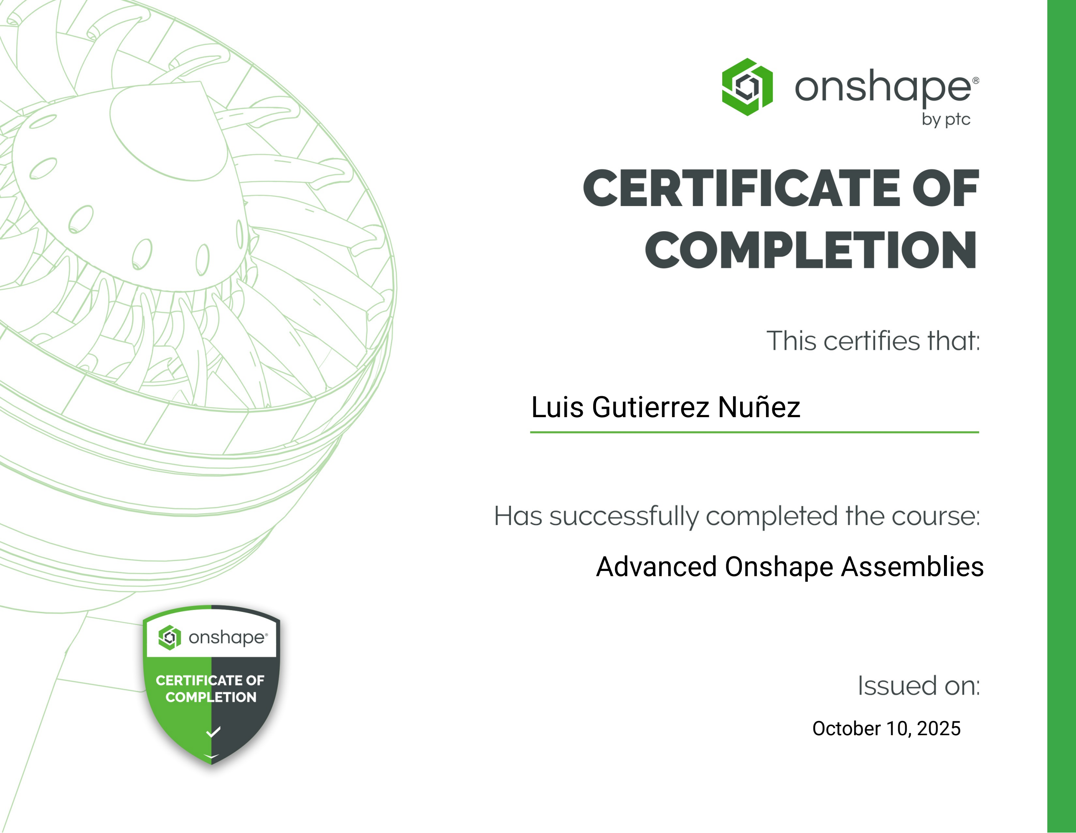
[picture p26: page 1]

Luis Gutierrez Nuñez

Advanced Onshape Assemblies

October 10, 2025

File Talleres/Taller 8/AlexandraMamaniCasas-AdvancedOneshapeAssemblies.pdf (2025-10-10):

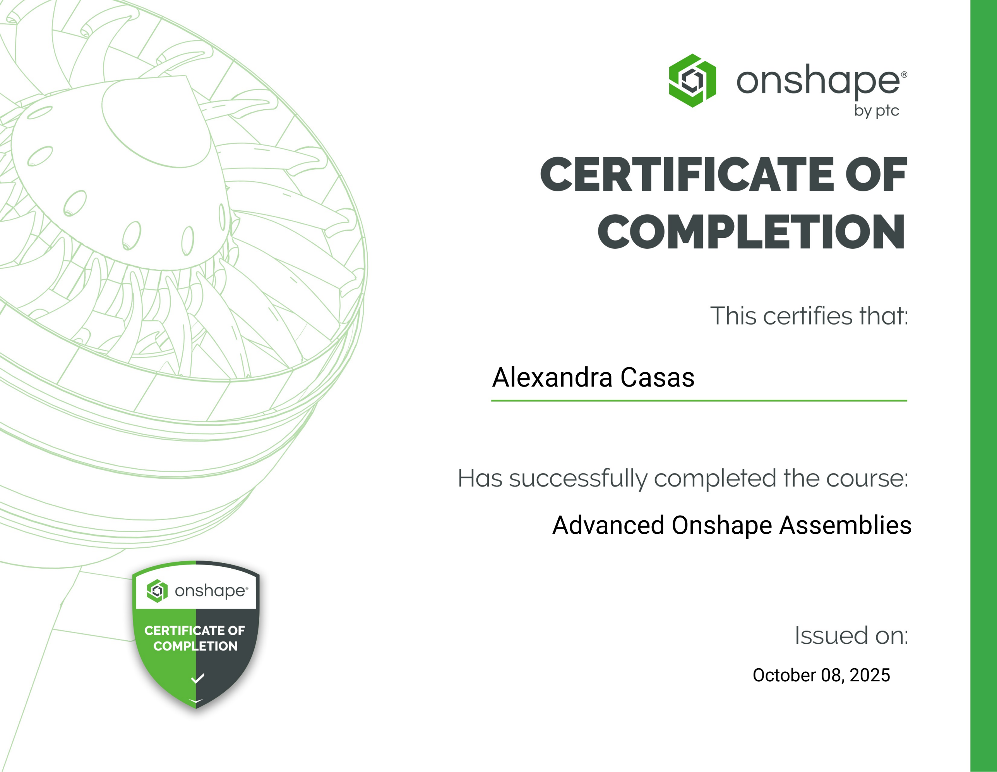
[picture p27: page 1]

Alexandra Casas

Advanced Onshape Assemblies

October 08, 2025

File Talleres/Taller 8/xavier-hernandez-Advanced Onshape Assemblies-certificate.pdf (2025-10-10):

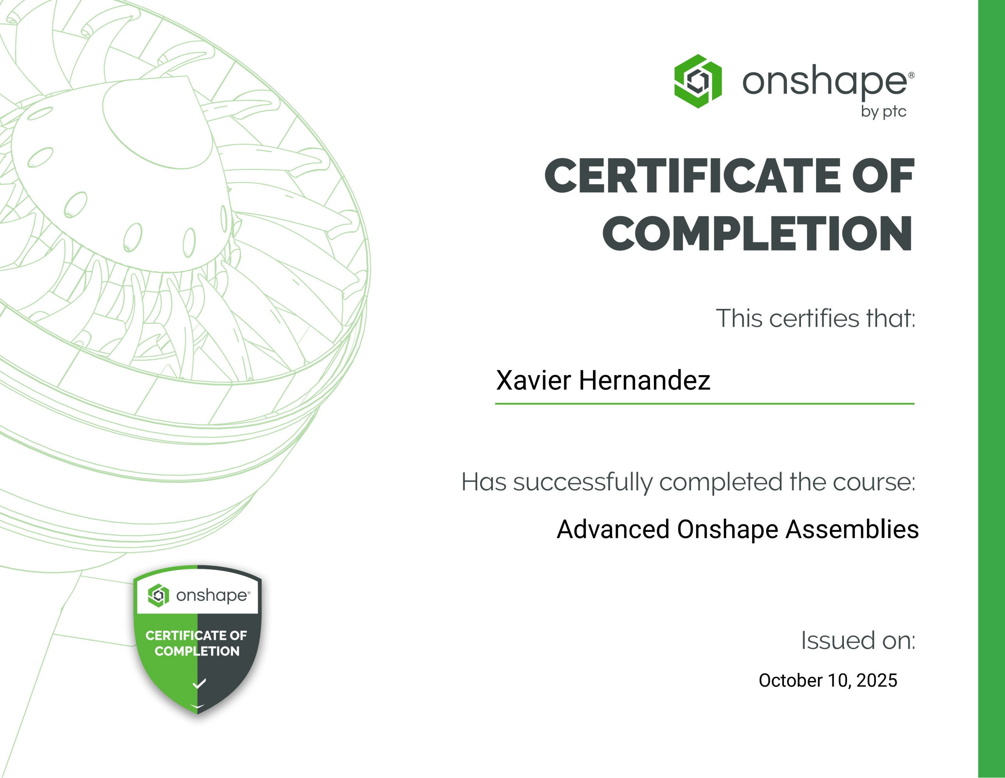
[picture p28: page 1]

Xavier Hernandez

Advanced Onshape Assemblies

October 10, 2025

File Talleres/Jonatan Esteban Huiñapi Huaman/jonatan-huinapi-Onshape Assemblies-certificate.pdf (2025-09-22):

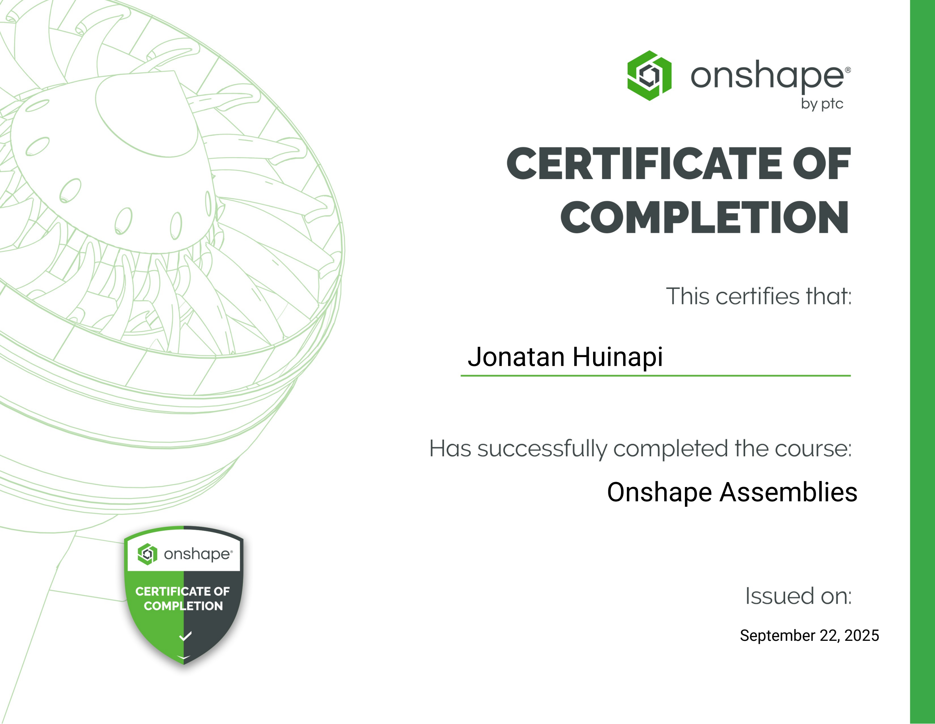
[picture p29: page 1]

Jonatan Huinapi

September 22, 2025

Onshape Assemblies

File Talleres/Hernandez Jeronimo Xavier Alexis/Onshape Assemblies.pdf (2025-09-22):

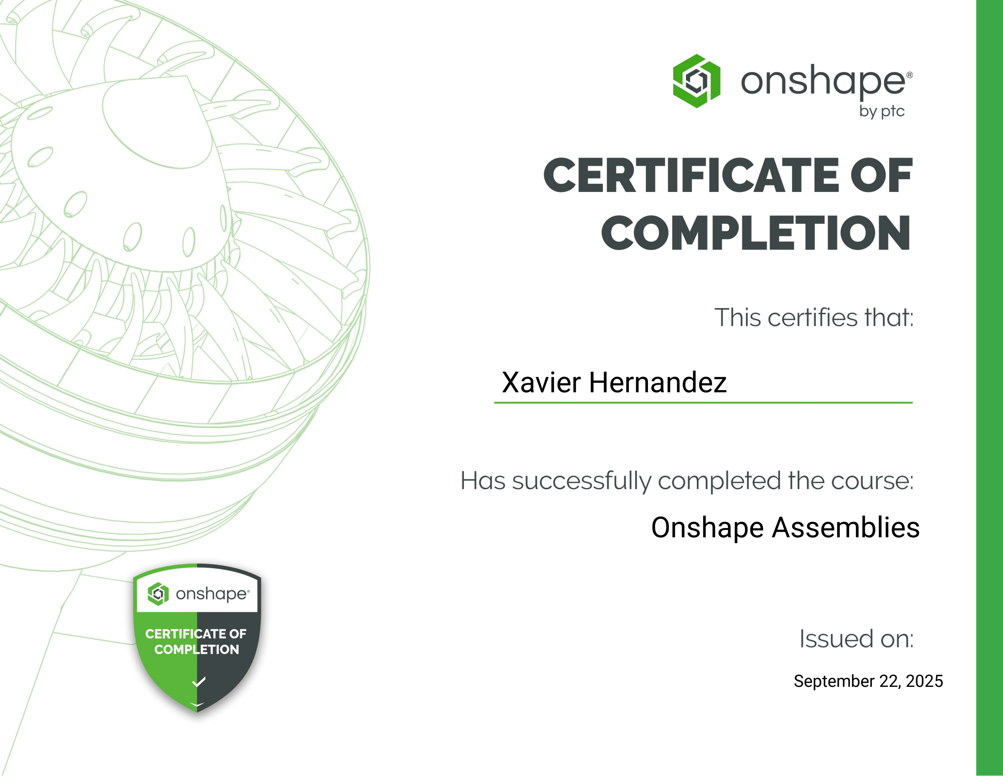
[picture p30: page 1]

Xavier Hernandez

September 22, 2025

Onshape Assemblies

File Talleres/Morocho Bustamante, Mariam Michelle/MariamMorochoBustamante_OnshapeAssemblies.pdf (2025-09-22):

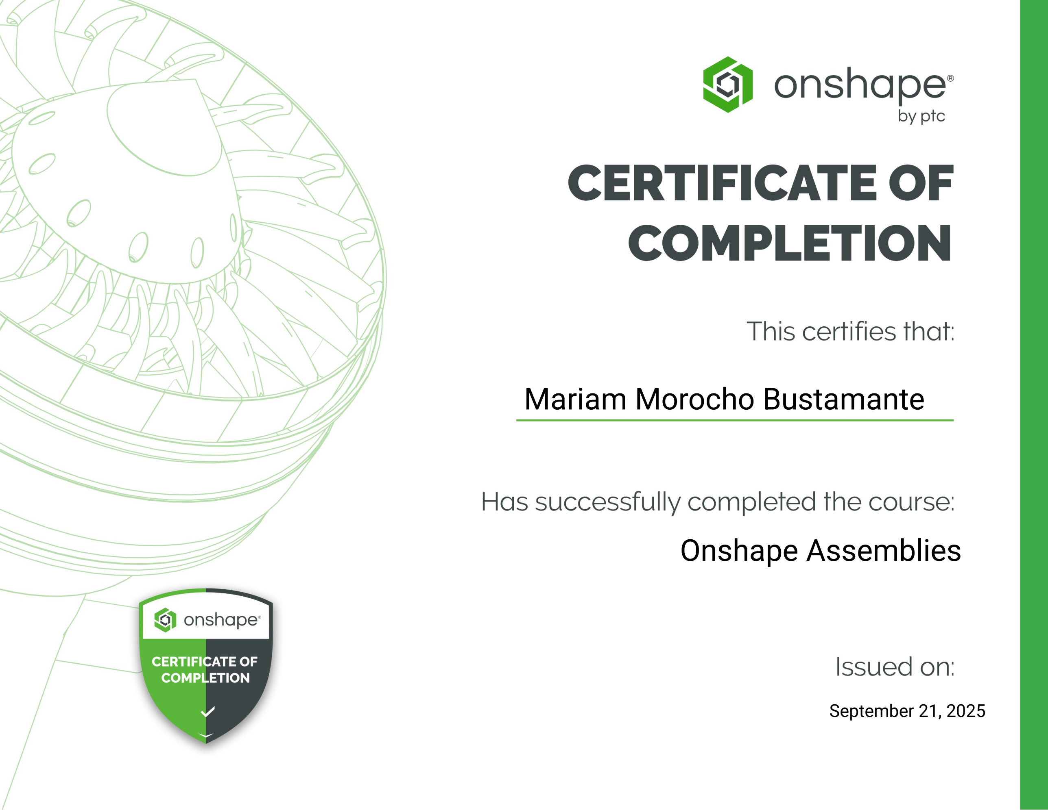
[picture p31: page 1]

Mariam Morocho Bustamante

September 21, 2025

Onshape Assemblies

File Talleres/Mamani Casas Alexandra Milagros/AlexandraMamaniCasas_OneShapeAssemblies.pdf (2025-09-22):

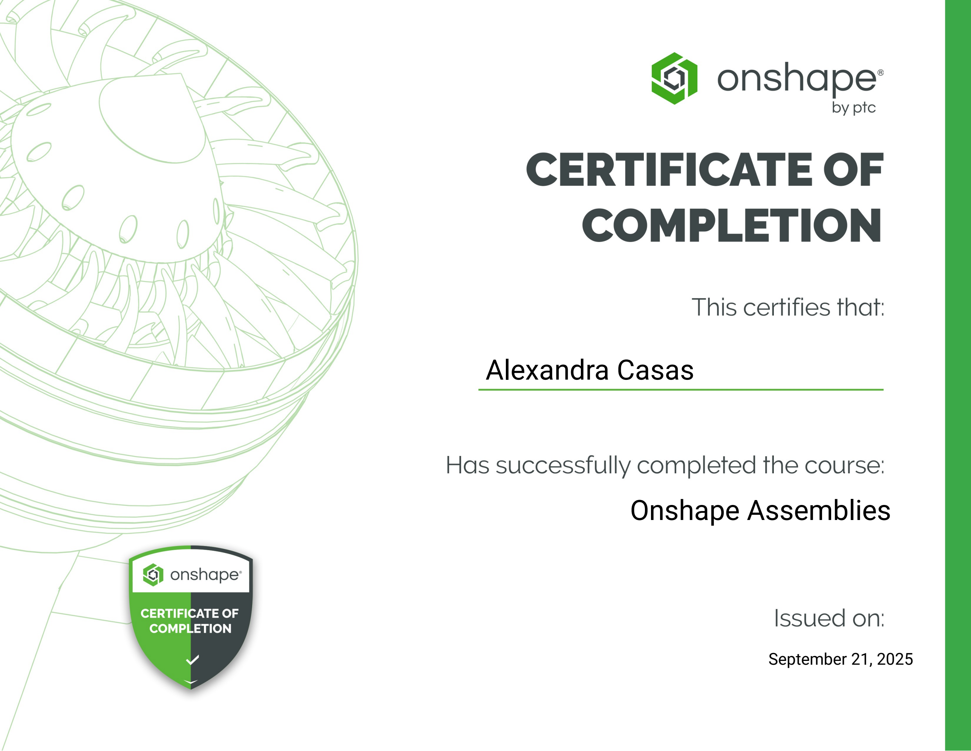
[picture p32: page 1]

Alexandra Casas

September 21, 2025

Onshape Assemblies

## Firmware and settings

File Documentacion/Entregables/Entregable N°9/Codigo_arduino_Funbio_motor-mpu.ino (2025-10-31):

#include <Wire.h>
#include <MPU9250.h>

// ------------------ IMU ------------------
MPU9250 mpu;                 // Librería tipo hideakitai
const uint8_t MPU_ADDR = 0x68; // 0x69 si AD0=HIGH
const unsigned long IMU_PERIOD_MS = 100; // cada 100 ms
unsigned long tIMU = 0;

// ------------------ RF (CH4 D0–D3) ------------------
// Usamos SOLO D0 y D1 como botones en pines 2 y 3
const byte BTN_FWD = 2;  // D0 del receptor
const byte BTN_REV = 3;  // D1 del receptor
const bool ACTIVE_HIGH = true;   
const unsigned long DEBOUNCE_MS = 50;
bool lastFwd = false, lastRev = false;
unsigned long tDebounce = 0;

// ------------------ L298N ------------------
const byte ENA = 11 ;  // PWM canal A
const byte IN1 = 10;
const byte IN2 = 9;
const byte ENB = 6;   // PWM canal B
const byte IN3 = 4;
const byte IN4 = 5;

const byte SPEED_PWM = 180;
const unsigned long RUN_MS = 2000; 

bool running = false;
int dir = 0; // 1 = adelante, -1 = atrás, 0 = parado
unsigned long tEnd = 0;

// ------------------ Helpers ------------------
inline bool btnRead(byte pin) {
  bool v = digitalRead(pin);
  return ACTIVE_HIGH ? v : !v;
}

void startRun(int d) {
  dir = d;
  if (dir == 1) {
    // Adelante: ambos motores mismo sentido
    digitalWrite(IN1, HIGH); digitalWrite(IN2, LOW);
    digitalWrite(IN3, HIGH); digitalWrite(IN4, LOW);
  } else {
    // Atrás
    digitalWrite(IN1, LOW);  digitalWrite(IN2, HIGH);
    digitalWrite(IN3, LOW);  digitalWrite(IN4, HIGH);
  }
  analogWrite(ENA, SPEED_PWM);
  analogWrite(ENB, SPEED_PWM);
  running = true;
  tEnd = millis() + RUN_MS;
}

void stopMotors() {
  analogWrite(ENA, 0);
  analogWrite(ENB, 0);
  // Freno activo (ambos LOW)
  digitalWrite(IN1, LOW); digitalWrite(IN2, LOW);
  digitalWrite(IN3, LOW); digitalWrite(IN4, LOW);
  running = false;
  dir = 0;
}

// ------------------ Setup ------------------
void setup() {
  Serial.begin(115200);

  // RF botones
  if (ACTIVE_HIGH) {
    pinMode(BTN_FWD, INPUT);
    pinMode(BTN_REV, INPUT);
  } else {
    pinMode(BTN_FWD, INPUT_PULLUP);
    pinMode(BTN_REV, INPUT_PULLUP);
  }

  // L298N
  pinMode(ENA, OUTPUT); pinMode(IN1, OUTPUT); pinMode(IN2, OUTPUT);
  pinMode(ENB, OUTPUT); pinMode(IN3, OUTPUT); pinMode(IN4, OUTPUT);
  stopMotors();

  // IMU
  Wire.begin();
  delay(50);
  if (!mpu.setup(MPU_ADDR)) {
    Serial.println(F("Error al iniciar MPU9250 (revisa direccion 0x68/0x69 y cableado)"));
  } else {
    Serial.println(F("MPU9250 listo"));
  }

  Serial.println(F("Sistema listo."));
}

// ------------------ Loop ------------------
void loop() {
  // --------- Lectura de botones y control no bloqueante ----------
  bool fwd = btnRead(BTN_FWD);
  bool rev = btnRead(BTN_REV);

  bool riseFwd = (fwd && !lastFwd);
  bool riseRev = (rev && !lastRev);

  unsigned long now = millis();

  if (!running && (now - tDebounce > DEBOUNCE_MS)) {
    if (riseFwd && !rev) {
      startRun(+1);
      tDebounce = now;
    } else if (riseRev && !fwd) {
      startRun(-1);
      tDebounce = now;
    }
  }

  if (running && now >= tEnd) {
    stopMotors();
  }

  lastFwd = fwd; lastRev = rev;

  // --------- IMU: leer e imprimir cada IMU_PERIOD_MS ----------
  if (now - tIMU >= IMU_PERIOD_MS) {
    tIMU = now;
    if (mpu.update()) {
      float ax = mpu.getAccX(); // en g
      float ay = mpu.getAccY();
      float az = mpu.getAccZ();

      // Estimación simple de ángulos con solo acelerómetro:
      float roll  = atan2(ay, az) * 180.0 / PI;                      // rotación alrededor de X
      float pitch = atan2(-ax, sqrt(ay*ay + az*az)) * 180.0 / PI;    // rotación alrededor de Y

      Serial.print(F("acc[g]: "));
      Serial.print(ax, 3); Serial.print(' ');
      Serial.print(ay, 3); Serial.print(' ');
      Serial.print(az, 3);
      Serial.print(F(" | roll: "));
      Serial.print(roll, 1);
      Serial.print(F(" deg | pitch: "));
      Serial.println(pitch, 1);
    }
  }
}

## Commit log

2025-08-22 Create Hi
    archivo de documentación
2025-08-27 Update Artritis
    Agregado sección de factores y análisis de la enfermedad
2025-08-27 Update Artritis
    Avance de información de prevención, diagnóstico y tratamiento
2025-08-28 Create Escoliosis
    Primer avance de la investigación sobre la escoliosis
2025-08-29 Rename Ficha de la enfermedad.docx to Escoliosis.docx
